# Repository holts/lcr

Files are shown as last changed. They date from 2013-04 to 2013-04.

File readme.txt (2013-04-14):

适合业余爱好者DIY高精度数字电桥 

http://www.crystalradio.cn/thread-231933-131-1.html
http://bbs.38hot.net/read.php?tid=13531
http://www.ourdev.cn/thread-5152439-1-2.html

程序为矿坛下的 gyp2000更改的 1602 V5.5

/**
  @page exampletemplate Project Example Template
  
  @verbatim
  ******************** (C) COPYRIGHT 2011 STMicroelectronics *******************
  * @file    readme.txt 
  * @author  MCD Application Team
  * @version V2.1.0
  * @date    18-November-2011
  * @brief   This sub-directory contains all the user-modifiable files 
  *          needed to create a new project linked with the STM8S/A  
  *          Standard Peripheral Library.
  ******************************************************************************
  * THE PRESENT FIRMWARE WHICH IS FOR GUIDANCE ONLY AIMS AT PROVIDING CUSTOMERS
  * WITH CODING INFORMATION REGARDING THEIR PRODUCTS IN ORDER FOR THEM TO SAVE
  * TIME. AS A RESULT, STMICROELECTRONICS SHALL NOT BE HELD LIABLE FOR ANY
  * DIRECT, INDIRECT OR CONSEQUENTIAL DAMAGES WITH RESPECT TO ANY CLAIMS ARISING
  * FROM THE CONTENT OF SUCH FIRMWARE AND/OR THE USE MADE BY CUSTOMERS OF THE
  * CODING INFORMATION CONTAINED HEREIN IN CONNECTION WITH THEIR PRODUCTS.
  ******************************************************************************
   @endverbatim

@par Project Example Template Description 

This example is used as a template that can be used as reference to build any new 
firmware development for all STM8S and STM8A product devices using the STM8S/A 
Standard Peripherals Library.

@par Directory contents 

This folder contains standard template projects for EWSTM8, STVD with Cosmic, 
STVD with raisonance and RIDE toolchains that compile the needed STM8S/A Standard
Peripheral's drivers plus all the user-modifiable files that are necessary to 
create a new project. 

  - Project/led/inc/stm8s_conf.h    Library Configuration file

  - Project/led/src/stm8s_it.c:     Source file containing the interrupt handlers (the 
                                     function bodies are empty in this template).

  - Project/led/inc/stm8s_it.h      Header file including all interrupt handlers prototypes.

  - Project/led/src/main.c          Main program
          
 @note
  - High-Density STM8A devices are the STM8AF52xx STM8AF6269/8x/Ax,
    STM8AF51xx, and STM8AF6169/7x/8x/9x/Ax microcontrollers where the Flash memory
    density ranges between 32 to 128 Kbytes
  - Medium-Density STM8A devices are the STM8AF622x/4x, STM8AF6266/68,
    STM8AF612x/4x, and STM8AF6166/68 microcontrollers where the Flash memory 
    density ranges between 8 to 32 Kbytes
  - High-Density STM8S devices are the STM8S207xx, STM8S007 and STM8S208xx microcontrollers
    where the Flash memory density ranges between 32 to 128 Kbytes.
  - Medium-Density STM8S devices are the STM8S105x and STM8S005 microcontrollers
    where the Flash memory density ranges between 16 to 32-Kbytes.
  - Low-Density STM8S devices are the STM8S103xx, STM8S003 and STM8S903xx microcontrollers
    where the Flash density is 8 Kbytes.
   
 * <h3><center>&copy; COPYRIGHT 2011 STMicroelectronics</center></h3>
 */

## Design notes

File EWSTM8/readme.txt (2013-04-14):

/**
  @page ewstm8 EWSTM8 Project Template for STM8S/A product devices
  
  @verbatim
  ******************* (C) COPYRIGHT 2011 STMicroelectronics ********************
  * @file    readme.txt
  * @author  MCD Application Team
  * @version V2.1.0
  * @date    18-November-2011
  * @brief   This sub-directory contains all the user-modifiable files needed
  *          to create a new project linked with the STM8S/A Standard Peripheral 
  *          Library and working with IAR Embedded Workbench for STM8 (EWSTM8)
  *          software toolchain.
  ******************************************************************************
  * THE PRESENT FIRMWARE WHICH IS FOR GUIDANCE ONLY AIMS AT PROVIDING CUSTOMERS
  * WITH CODING INFORMATION REGARDING THEIR PRODUCTS IN ORDER FOR THEM TO SAVE
  * TIME. AS A RESULT, STMICROELECTRONICS SHALL NOT BE HELD LIABLE FOR ANY
  * DIRECT, INDIRECT OR CONSEQUENTIAL DAMAGES WITH RESPECT TO ANY CLAIMS ARISING
  * FROM THE CONTENT OF SUCH FIRMWARE AND/OR THE USE MADE BY CUSTOMERS OF THE
  * CODING INFORMATION CONTAINED HEREIN IN CONNECTION WITH THEIR PRODUCTS.
  ******************************************************************************
  @endverbatim
 
 @par Directory contents

 - project .ewd/.eww/.ewp: A pre-configured project file with the provided library 
                           structure that produces an executable image with IAR 
                           Embedded Workbench.

 @par How to use it ?

 - Open the Project.eww workspace.
 - In the workspace toolbar select the project configuration:
     - stm8s103: to configure the project for STM8S103 Low-density devices. 
     - stm8s903: to configure the project for STM8S903 Low-density devices.
     - stm8s105: to configure the project for STM8S Medium-density devices.
     - stm8s207: to configure the project for STM8S207 High-density devices.
     - stm8s208: to configure the project for STM8S208 High-density devices.
     - stm8af52ax: to configure the project for STM8AF52Ax High-density devices.
     - stm8af62ax: to configure the project for STM8AF62Ax High-density devices.
     - stm8af626x: to configure the project for STM8A Medium-density devices.
     @note The needed define symbols for these configurations are already declared in the
           preprocessor section.

 - Rebuild all files: Project->Rebuild all
 - Load project image: Project->Debug
 - Run program: Debug->Go(F5)

  @note
  - High-Density STM8A devices are the STM8AF52xx STM8AF6269/8x/Ax,
    STM8AF51xx, and STM8AF6169/7x/8x/9x/Ax microcontrollers where the Flash memory
    density ranges between 32 to 128 Kbytes
  - Medium-Density STM8A devices are the STM8AF622x/4x, STM8AF6266/68,
    STM8AF612x/4x, and STM8AF6166/68 microcontrollers where the Flash memory 
    density ranges between 8 to 32 Kbytes
  - High-Density STM8S devices are the STM8S207xx, STM8S007 and STM8S208xx microcontrollers
    where the Flash memory density ranges between 32 to 128 Kbytes.
  - Medium-Density STM8S devices are the STM8S105x and STM8S005 microcontrollers
    where the Flash memory density ranges between 16 to 32-Kbytes.
  - Low-Density STM8S devices are the STM8S103xx, STM8S003 and STM8S903xx microcontrollers
    where the Flash density is 8 Kbytes.
   
 * <h3><center>&copy; COPYRIGHT 2011 STMicroelectronics</center></h3>
 */

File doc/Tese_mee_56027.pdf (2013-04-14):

## Dissertation submitted for obtaining the degree of Master in Electronic Engineering

## Impedance Measuring System based on a dsPIC

## José Carlos Sequeira Martins dos Santos

## November 2009

### President : Prof. Moisés Simões Piedade Supervisor: Prof. Pedro Miguel Pinto Ramos Members: Prof. Rui Manuel Rodrigues Rocha

## Jury

i

# Acknowledgements

Above all, I would like to thank my parents, my sister and the rest of my family for the

patience and support demonstrated throughout these five long years of the course. Without

them I could not have made it so far.

I want to thank my coworkers and friends for always being there to help me in the

difficult moments and for providing an excellent work environment. They are certain one of the

best group of people I ever had the pleasure of meeting.

I thank Professor Pedro Ramos for the support and encouragement given throughout

the work, and for giving me the opportunity to develop it.

Finally I would like to thank Professor Moisés Piedade for is undying efforts for creating

the necessary conditions for all to develop their work.

Thank you all.

ii

# Abstract

Impedance measurement is currently one of the research and development areas under

the work developed by the Instrumentation and Measurement Group of the Institute of

Telecommunications. The existing measurement systems are either too costly or don’t have

enough accuracy and make measurements in a reduced frequency range.

This work is related to a project that is underway: IMPANA – Development and

implementation of an impedance analyzer based on analog to digital conversion and powerful

signal processing algorithms (Financed by the Foundation for Science and Technology,

PTDC/EEA-ELC/72875/2006 from 01-Sep-2006 to 31-Aug-2010).

With the execution of this work one seeks to obtain a device capable of making

impedance measurements at multiple frequencies. The device is based on a dsPIC (Digital

Signal Peripheral Interface Controller) from Microchip as a central processing unit. A DDS

(Direct Digital Synthesizer) is used to generate the stimulus signal of the measurement circuit,

which has the reference impedance and the impedance under measurement. The voltage

across the two impedances is amplified by programmable gain instrumentation amplifiers,

whose outputs will then be digitized by analog to digital converters. The signal processing for

the determination of the unknown impedance is performed using a sine-fitting algorithm. The

dsPIC is connected through RS-232 to a personal computer (PC), where the user can monitor

the resulting samples of the measurement and view the measurement results.

Keywords: Impedance measurement, dsPIC, ADC, Sine-fitting

iii

# Resumo

A medição de impedâncias é actualmente uma das áreas de investigação e

desenvolvimento, no âmbito dos trabalhos desenvolvidos pelo Grupo de Instrumentação e

Medidas no Instituto de Telecomunicações. Os sistemas de medição existentes ou são

demasiado dispendiosos ou não têm exactidão suficiente e efectuam medições numa gama de

frequências reduzida.

Este trabalho enquadra-se num projecto que se encontra a decorrer: IMPANA –

Development and implementation of an impedance analyzer based on analog to digital

conversion and powerful signal processing algorithms (Financiado pela Fundação para a

Ciência e Tecnologia, PTDC/EEA-ELC/72875/2006 de 01-Set-2006 a 31-Ago-2010).

Com a execução deste trabalho pretende-se obter um dispositivo capaz de efectuar

medições de impedâncias a diversas frequências. O dispositivo é baseado num dsPIC (Digital Signal Peripheral Interface Controller) da Microchip como unidade central de processamento. É

utilizado um DDS (Direct Digital Synthesizer), sendo responsável por gerar o sinal de estímulo

do circuito de medição, que tem a impedância de referência e a impedância a medir. As

tensões aos terminais das duas impedâncias são amplificadas por amplificadores de

instrumentação de ganho programável, cujas saídas são digitalizadas por conversores

analógico-digitais. O processamento de sinal necessário para a determinação da impedância

desconhecida é efectuado recorrendo ao algoritmo de adaptação de sinusóides. O dsPIC é

ligado através de RS-232 a um computador pessoal (PC), onde o utilizador pode monitorizar as

amostras resultantes da medição e visualizar os resultados da medição.

Palavras – Chave: Medição de impedâncias, dsPIC, ADC, Sine-fitting

iv

# Table of Contents

v

vi

# List of Figures

Fig. 1.2 - Representation of inductive and capacitive reactance in the impedance vector plane. 2

Fig. 1.3 - An example of linear (a) and rotational (b) EIM measurements being performed on a

Fig. 2.4 - RF I-V method. (a) Low impedance measurement; (b) High impedance measurement

Fig. 3.1 - Measurement circuit. | is the impedance under measurement and | is the reference

Fig. 3.2 – Development tools for the work. (a) Explorer 16 Development Board; (b) MPLAB ICD

Fig. 3.5 - High-pass filter used to eliminate the DC component from the output signal of the

Fig. 3.10 - Circuit of a differential amplifier used to add a DC offset to the signal to acquire. .... 21

Fig. 4.2 - Behavior of an acquired signal spectrum in the case of no under sampling and in the

vii

Fig. D.1 - Schematic of the complete system. Square 3 represents the hardware for the USB

viii

# List of Tables

ix

# Acronyms

Acronym | Meaning
ADC | Analog to Digital Converter
ASCII | American Standard Code for Information Interchange
DAC | Digital to Analog Converter
DC | Direct Current
DDS | Direct Digital Synthesizer
DSC | Digital Signal Controller
DSP | Digital Signal Processor
dsPIC | Digital Signal Peripheral Interface Controller
FFT | Fast Fourier Transform
IDE | Integrated Development Environment
IpDFT | Interpolated Discrete Fourier Transform
MCU | Microcontroller
MIPS | Million Instruction Per Second
OP-AMP | Operational Amplifier
PC | Personal Computer
PCB | Printed Circuit Board
PGIA | Programmable Gain Instrumentation Amplifier
RAM | Random Access Memory
ROM | Read Only Memory
SPI | Serial Peripheral Interface
THD | Total Harmonic Distortion

# 1 – Introduction

## 1.1– Impedance Concepts Overview

Impedance is an important parameter used to characterize electronic circuits,

components, and the materials used to make components [1]. Impedance (Z) is generally

defined as the total opposition a device or circuit offers to the flow of an alternating current (AC)

at a given frequency, and is represented as a complex quantity which can be graphically

represented on a vector plane – Fig. 1.1. An impedance vector consists of a real part

(resistance, R) and an imaginary part (reactance, X).

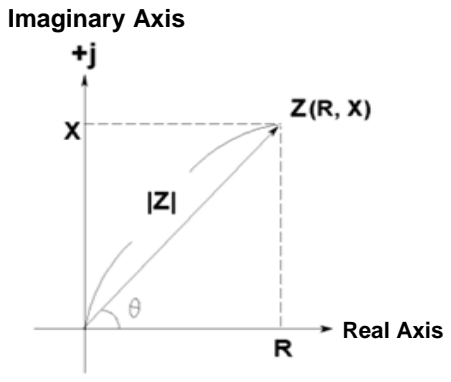
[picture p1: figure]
Real Axis; Imaginary Axis

Fig. 1.1 - Impedance vector plane (taken from [1]).

Impedance can be expressed using the rectangular form,

or the polar form as a magnitude and phase angle,

Equations (1.3) to (1.6) show the mathematical relationships between R, X, |Z| and θ.

The unit of impedance is the ohm (Ω).

Reactance can take two forms: inductive (XL) and capacitive (XC). Fig. 1.2 represents

the two possible forms of reactance and the correspondent representation in the impedance

vector plane for a given frequency.

Fig. 1.2 - Representation of inductive and capacitive reactance in the impedance vector plane.

## 1.2– Applications of Impedance Measurements

As the world of technology evolves, so does its need for improved measurement

techniques. One of the major areas of investigation that has been growing for the past few

years is impedance measurement. With a wide spectrum of applications, from medicine to

electronics, impedance measurement is surely an area worth researching.

In the field of medicine, impedance measurement can be used in electrical impedance

myography (EIM), which is a non-invasive technique for neuromuscular assessment [2], [3]. It

enables the detection of degenerative neuromuscular diseases. Measurements can be taken

painlessly and non-invasively using electrodes that are placed on top of the skin. They can also

be taken from different parts of the body at the bedside. In this technique, a low-intensity

alternating current is applied to a muscle and the consequent voltage difference is evaluated.

From these measurements one can calculate the impedance of the underlying muscle and

make inference about its structure.

There are two main methods used in this technique: linear EIM and rotational EIM.

Linear EIM involves placing multiple pairs of voltage electrodes in a line directly above the

muscle or muscle group of interest – Fig. 1.3(a). The current electrodes are placed so that

current must flow in parallel to this line. The voltages at each point along the muscle are

compared during analysis. Both single frequency (typically 50 kHz) and multi-frequency

measurements can be taken.

Rotational EIM measures impedance at multiple angles relative to the direction of

muscle fibers – Fig. 1.3(b). Both the current and voltage electrodes need to be rotated as they

must be kept in line with each other at all angles to control the direction of current flow. For this

method multi-frequency measurements are usually taken and then the average phase across all

frequencies is compared at each different angle.

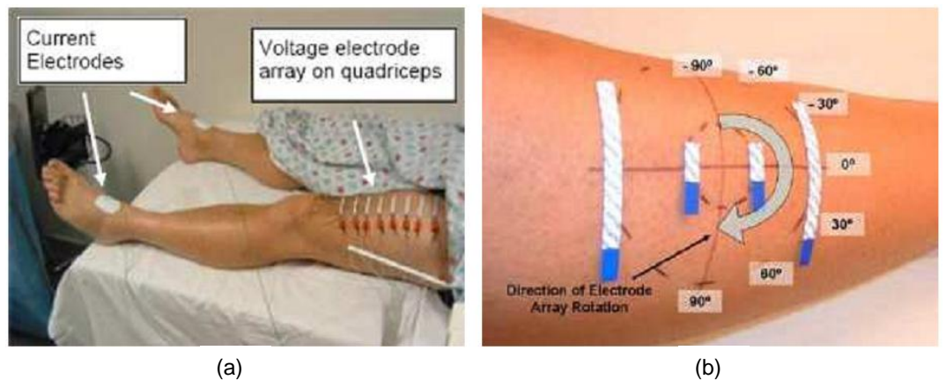
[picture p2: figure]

Fig. 1.3 - An example of linear (a) and rotational (b) EIM measurements being performed on a patient (taken from [3]).

Impedance measurement can also play an important part in civil engineering. It can be

used to measure the level of corrosion in some materials such as reinforced steel in concrete

[4]. A concrete Surface-based Measurement Method (SMM) is used as nondestructive

technique to determine the deterioration of structures and study the corrosion process. The

method is able to determine the corrosion state of the reinforcing bars, as well as the resistivity

of the concrete itself, from the concrete surface and with no need of connection to the

reinforcement. It uses an array of four electrodes, equally spaced, and placed on the surface of

the concrete to indirectly measure the frequency-dependent impedance between the reinforcing

steel bars and the concrete – Fig. 1.4. Alternating current, varied over a wide range of

frequencies, is injected between the two outer electrodes, and the voltage difference produced

by the current flow is measured across the two inner electrodes. This voltage presents an angle

phase shift with respect to the current. As the current is injected into the concrete, the steel bar

surface becomes polarized creating a net dipole which is added to the voltage read by the inner

electrodes – Fig. 1.5.

It is important to notice that the measured impedance on the concrete surface does not

reflect directly the interfacial impedance, because it is influenced by the concrete resistivity.

However, a change in the corrosion state of a steel bar, will be reflected in the measurement on

the concrete surface, and given the concrete resistivity and measurement geometry, the

impedance response is unique to each interfacial impedance.

Fig. 1.4 - Four-electrode array placed on the concrete surface (taken from [4]).

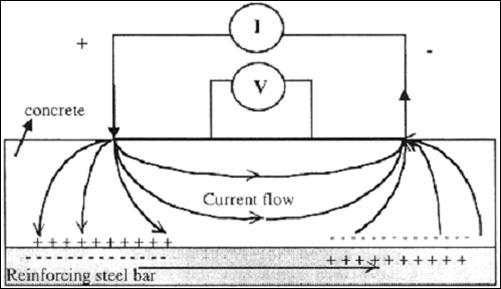
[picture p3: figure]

Fig. 1.5 - Net dipole created by the four-electrode array (taken from [4]).

## 1.3– Motivation

The technological advances of the past few years have improved the performance of

data acquisition systems to a point where it is possible to implement cheaper ways to make the

same measurements as dedicated expensive equipment, without relevant degradation of the

system accuracy.

The continuous improvement in performance of new devices, such as Analog to Digital

Converters (ADCs), combined with more powerful signal processing techniques, are some of

the factors that have contributed to this fact.

Typical measuring techniques/instruments are either too costly, or don’t have enough

accuracy and have a reduced frequency range. Agilent Technologies is one of the leading

companies for measurement systems. Its simplest impedance measuring system [5] covers

frequencies from 40 Hz up to 110 MHz with a basic accuracy of 0.08 %. However, its price of

nearly 30.000€ makes the system well beyond the budget capabilities of many companies and

research institutes.

Therefore there has been an increasing demand for low cost impedance measuring

systems capable of performing measurements at a broad range of frequencies but still with

comparable accuracy to that of sophisticated impedance measurement equipment.

## 1.4– Work Goals

This work seeks to develop, implement and characterize a low-cost device capable of

measuring impedances at a wide range of frequencies by using ADCs and a dsPIC as a central

processing unit to both control all the necessary hardware of the measuring circuit and run the

sine fitting algorithm necessary to the proper measurement of the impedance. A personal

computer is also used, which acts as interface between the user and the device, allowing the

monitoring of the acquired samples.

The device has to be able to measure impedances in the frequency range from 500 Hz

to 200 kHz. The amplitude of the impedances to be measured is intended to be between 100 Ω

and 10 kΩ.

The dsPIC is responsible for: i) controlling the stimulus module of the measurement

circuit through a DDS which is responsible for generating the sine signal with the measurement

frequency; ii) controlling the programmable gain instrumentation amplifiers (PGIAs) that amplify

the voltage at the terminals of the two impedances (reference impedance and impedance under

measurement); iii) controlling and communicating with the ADCs responsible for the

digitalization of the output voltage from the PGIAs; iv) applying the algorithm to determine the

amplitudes and phases of the sinusoidal signals across each impedance (sine-fitting); v)

applying the algorithms to correct systematic errors; vi) transmitting the results to a PC through

a RS-232 connection.

In the end the user will be able to control the device in order to decide at which

frequency he wants to perform the impedance measurement.

## 1.5- Thesis Organization

This thesis is organized as follows:

In Section 2, the State Of The Art for impedance measurement systems is presented. It

is given an overview of the existing impedance measurement methods. A few points regarding

sine-fitting algorithms are discussed and finally it is presented a new impedance measurement

method that is currently under development.

In Section 3 it is presented the system’s architecture, where the measurement circuit

and method is explained, along with all the hardware used in the system.

Section 4 describes in detail all the algorithms implemented, for proper measurement of

the unknown impedance.

In Section 5 the implemented control software running on a PC is described.

In Section 6 the experimental results obtained by the device are compared to the results

obtained with a commercially available device.

The conclusions of the work are presented in Section 7.

Finally, Section 8 describes the proposed future work.

# 2 – State Of The Art

Impedance measurement systems are used to test electronic components, circuits and

materials. They can also be used to measure sensor’s outputs that translate physical quantities

into electrical impedance.

## 2.1– Impedance Measurement Methods

Several impedance measurement methods exist. Traditional methods include: bridge,

resonant, I-V, RF I-V, network analysis and auto balancing bridge [1].

The bridge method applies the setup presented in Fig. 2.1.

Fig. 2.1 - Bridge method setup (taken from [1]).

When no current flows through the detector (D), the value of the unknown impedance

Zx can be obtained by the relationship of the other bridge elements by

Various types of bridge circuits, employing combinations of L, C, and R components as

the bridge elements, are used for various applications.

This is a low cost method with a wide frequency coverage (DC to 300 MHz) by using

different types of bridges. However, it needs to be manually balanced by experienced

technicians.

In the resonant method, the setup from Fig. 2.2 is used.

Fig. 2.2 - Resonant method setup (taken from [1]).

When the circuit is adjusted to resonance by adjusting the tuning capacitor C, the

unknown impedance Lx and Rx values are obtained from the test frequency, the C value, and

the Q value. Q represents the quality factor of the inductance. Q is measured directly using a

voltmeter placed across the tuning capacitor. Because the loss of the measurement circuit is

very low, Q values as high as 1000 can be measured.

It presents a good Q accuracy up to high Q, but the need for tuning to resonance and its

low impedance measurement accuracy are clear disadvantages of this method. It has an

applicable frequency range from 10 kHz to 70 MHz.

The I-V or volt-ampere method has the measurement setup presented in Fig. 2.3.

Fig. 2.3 - I-V method setup (taken from [1]).

The unknown impedance Zx can be calculated by using the measured voltages V1 and

V2 – equation (2.2).

The current value I is calculated using the voltage measurement (V2) across an

accurately known low value resistor, R. In practice a low-loss transformer is used in place of R

to prevent the effects caused by placing a low value resistor in the circuit. The transformer,

however, limits the low end of the applicable frequency range (10 kHz to 100 MHz).

This method has the advantage of being able to perform a grounded device

measurement and is suitable for probe type test needs.

The measurement setup for the RF I-V method is presented in Fig. 2.4.

Fig. 2.4 - RF I-V method. (a) Low impedance measurement; (b) High impedance measurement (taken from [1]).

The RF I-V measurement method is based on the same principle as the I-V method, but

it is configured in a different way by using an impedance matched measurement circuit (50 Ω)

and a precision coaxial test port for operation at higher frequencies. There are two types of

configurations which are suited for low impedance – Fig. 2.4(a), and high impedance – Fig.

2.4(b), measurements. The impedance Zx is derived from the measured voltage values V1 and

V2, as illustrated. Equation (2.3) refers to the low impedance measurement arrangement and

(2.4) refers to the high impedance measurement arrangement.

Similarly to the I-V method, the current that flows through Zx is calculated from the

voltage measurement across a known low value resistor, R. Just like before, in practice, a low

loss transformer is used in place of the low value resistor, R. The low end of the frequency

range of this method (1 MHz to 3 GHz) is limited by this transformer.

This method presents a high accuracy (typically 1%) and a wide impedance range at

high frequencies.

The network analysis method has the measurement setup presented in Fig. 2.5.

Fig. 2.5 - Network analysis method setup (taken from [1]).

In this method the reflection coefficient is obtained by measuring the ratio between the

incident signal and the reflected signal. A directional coupler or bridge is used to detect the

reflected signal and a network analyzer is used to supply and measure the signals. Since this

method measures reflection at the impedance Zx, it is usable in a higher frequency range

(300 kHz and above).

This method presents a good accuracy when the unknown impedance is close to the

characteristic impedance of the network, but it has the disadvantage of requiring a recalibration

procedure when the measurement frequency changes. It also has a narrow impedance

measurement range.

The auto balancing bridge method setup is shown in Fig. 2.6.

Fig. 2.6 - Auto balancing bridge setup (taken from [1]).

The current, flowing through the impedance Zx, also flows through the resistor R. The

potential at the “L” point is maintained at zero volts (thus called a “virtual ground”), because the

current through R balances with the Zx current by operation of the I-V converter amplifier. The

Zx impedance is calculated by using the voltage measured at the “H” point and the voltage

across R.

In practice, the configuration of the auto balancing bridge differs for each type of

instrument. Generally LCR meters, in a low frequency range typically below 100 kHz, employ a

simple operational amplifier for its I-V converter. This type of instrument has a disadvantage in

accuracy, at high frequencies, because of the amplifier’s limits in terms of performance.

Wideband LCR meters and impedance analyzers employ an I-V converter consisting of

sophisticated null detector, phase detector, integrator (loop filter) and vector modulator to

ensure a high accuracy for a broad frequency range over 1 MHz. This type of instrument can attain a maximum measurement frequency of 110 MHz. These instruments have a minimum

measurement frequency of about 20 Hz.

This method has a high accuracy over a wide impedance measurement range and is

capable of performing a grounded device measurement.

Agilent Technologies, one of the leading companies of the instrumentation market, has

several commercially available products that apply some of the methods described above. The

4287A RF LCR Meter [6] uses an RF I-V method, the 4395A Network/Spectrum/Impedance

Analyzer [7] uses a network analysis method and the 4294A Precision Impedance Analyzer [5]

uses an auto balancing bridge method.

## 2.2– Sine-Fitting Algorithms

The objective of sine-fitting algorithms is to obtain a set of parameters corresponding to

the analytical expression of a sine signal while minimizing the sum of the squared errors

between the estimated parameters and the acquired samples.

The three-parameter and the four-parameter sine-fitting algorithms were standardized in

[8]. The first is a non-iterative algorithm that with the knowledge of the frequency estimates the

amplitude, the phase and the DC component of the signal. The second also estimates the

frequency of the signal, but requires an iterative process to obtain the best estimation of the

parameters. Because it uses an iterative process, the initial estimates of the parameters are

critical for the convergence of the algorithm. In applications that use two channels with a

common frequency, which is the case of this work, all the information from both records should

be used to obtain a better estimative of the frequency. This can be done using a seven-

parameter sine-fitting algorithm [9], which is an iterative algorithm similar to the four-parameter

algorithm. The difference is that the seven-parameter algorithm estimates the amplitude, phase

and DC component of both signals, plus the common frequency. The effectiveness of this

algorithm was demonstrated in [10], when compared with the application of two four-parameter

algorithms.

The seven-parameter sine-fitting algorithm was the selected algorithm for the purposes

of this work and it will be described in more detail later on.

## 2.3– New Impedance Measurement Method

In many applications it is necessary to accurately measure an unknown impedance

corresponding to a sensor output. In [11] a new method for impedance measurements using

DSP-based ellipse-fitting algorithms is described. This method uses a sine wave generator to

supply current to the serial circuit composed by the reference impedance and the impedance to

be measured. It also uses two instrumentation amplifiers that sense the differential voltages at

the reference impedance and the impedance to be measured, a two channel ADC that digitizes

the signals coming from the instrumentation amplifiers and a DSP (Digital Signal Processor) as a central processing unit. A personal computer is also used to communicate with the DSP

through an RS-232 connection. Fig. 2.7 shows the measurement setup.

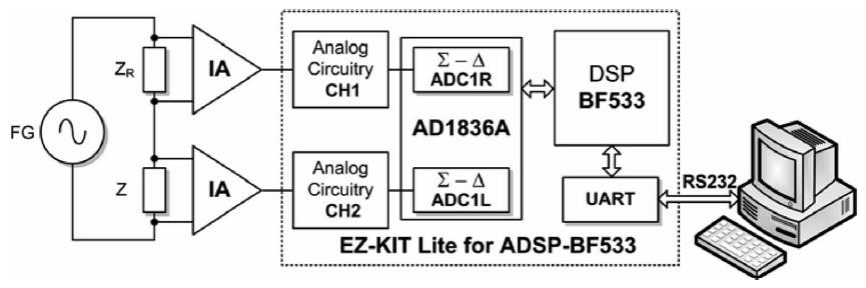
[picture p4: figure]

Fig. 2.7 - Measurement setup (taken from [11]).

In [11] the algorithm used to perform the signal processing is the ellipse-fitting algorithm.

The ellipse-fitting algorithm is not iterative since it does not estimate the frequency of the

signals. Because the frequency is imposed by the generator, there is no need to estimate it.

This makes the ellipse-fitting algorithm very efficient, and since it can be modified from its

original form [12] to have very low memory requirements, it turns out to be a very fast signal

processing algorithm allowing the system to perform high speed measurements.

This methodology, given the nature of the devices used in the system, is a low-cost

alternative to dedicated impedance measurement equipment, but with comparable accuracy.

This thesis applies a measurement method similar to that described above, except for

the algorithm responsible for the signal processing. In the case of this thesis the selected

algorithm is the seven-parameter sine-fitting algorithm. The measurement setup used in this

thesis will be explained in detail later on.

# 3 – System’s Architecture

## 3.1 – Measurement Circuit and Method

The impedance measurement circuit used to ascertain the value of the unknown

impedance is presented in Fig. 3.1.

Fig. 3.1 - Measurement circuit. | is the impedance under measurement and | is the reference impedance.

The measurement method is based in the volt-ampere method [1], in which the module

of the unknown impedance can be determined by knowing the module of the reference

impedance and the ratio between the amplitude of the sine signal across the impedance under

measurement and the amplitude of the sine signal across the reference impedance. The phase

angle of the unknown impedance is calculated based in the phase angle of the reference

impedance and the phase difference between the sine signal across the impedance under

measurement and the sine signal across the reference impedance [13]. The method used is

similar to that in [11], but in this case a dsPIC is used as a processing unit and a DDS is used to

inject current in the circuit.

The measurement procedure is done according to the following steps:

(i) The dsPIC controls the DDS in order to generate a sine wave with the user-

defined measurement frequency.

(ii) The dsPIC selects the gains of the amplifiers according to the magnitudes of

the signals across the reference impedance and the impedance under

measurement.

(iii) The dsPIC controls the ADCs to acquire simultaneously the samples (in this

case 1024 per channel) of the output voltage of the PGIAs, which amplify the

signals across the reference impedance (PGIA 1) and the unknown impedance

(PGIA 2). The gains of both amplifiers are set by the dsPIC to maximize the

amplitudes of the signals, but with care to avoid saturation of the digitizing

channels.

(iv) | A seven parameter sine-fitting algorithm is applied in order to determine the
amplitudes | and phases | of the sine waves that best fit the acquired
samples of both channels ( | ).

(v) The modulus and phase angle of the impedance under measurement are

calculated by

Once all the calculations are done, the experimental results of the measurement are

transmitted to the PC.

The entire measurement circuit is represented in the schematic from Fig. C.1 in

appendix C.

## 3.2 – Processing Unit

The processing unit used in the device is a dsPIC which is a Digital Signal Controller

(DSC). A DSC is a single-chip, embedded controller that integrates the control attributes of a

Microcontroller (MCU) with the computation and throughput capabilities of a Digital Signal

Processor (DSP) in a single core. In terms of performance and price, a dsPIC is somewhere in

the middle of the PIC MCU (in the low end) and the DSP (in the high end), and so it achieves

the best of both worlds making it perfect for this embedded control application.

The dsPIC used in this work is a 16-bit dsPIC33FJ256GP710 microcontroller from

Microchip - Fig. 3.2(c). It has a throughput up to 40 MIPS, 256 kB of flash program memory and

30 kB of RAM (Random Access Memory). It also includes two 12-bit ADCs capable of

conversion speeds up to 500 kS/s.

The Explorer 16 Development Board from Microchip - Fig. 3.2(a), in which the dsPIC is

connected to, is used as a prototyping tool to help implement the device. The board allows easy

connection to an MPLAB ICD 2 In-Circuit Debugger - Fig. 3.2(b). This is a development tool

allowing the programming of the dsPIC, and is capable of debugging ASM and C source code.

The application code for the device is written in C language on the MPLAB Integrated

Development Environment (IDE), and then it is loaded to the dsPIC using the MPLAB ICD 2.

The total program memory required for the execution of the developed code for this

work is 16578 bytes, and the total data memory is 20850 bytes. These memory requirements

are well within the memory capabilities of the dsPIC. The data memory required is so high given

the nature of some of the algorithms used in this work. Each algorithm and their memory

requirements will be explained in more detail in Section 4.

The hardware associated with the processing unit is represented in square 1 in the

schematic from Fig. D.1 in appendix D.

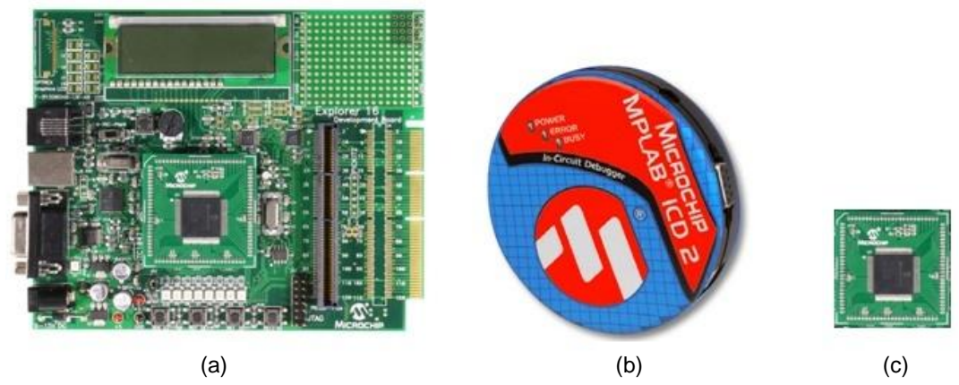
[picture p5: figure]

Fig. 3.2 – Development tools for the work. (a) Explorer 16 Development Board; (b) MPLAB ICD 2 In-Circuit

Debugger; (c) 16-bit dsPIC33FJ256GP710.

## 3.3– Stimulus Module

The module used to stimulate the measurement circuit is a DDS. A DDS is an electronic

programmable waveform generator, which produces a signal from a fixed-frequency clock

source. The waveform is digitally generated by using sampling techniques. Typically it is used to

generate a sine wave, although it can be used to synthesize any other periodic waveforms such

as triangular and square signals.

A DDS is basically composed by a phase accumulator, a phase to amplitude converter

and a digital to analog converter (DAC). A low-pass filter may also be included to eliminate

unwanted high frequency spectral components from the analog output. Fig. 3.3 shows the block

diagram of a general DDS.

Fig. 3.3 - Block diagram of a general DDS.

The DDS operation consists of the following: the phase accumulator is incremented by

using a clocked binary adder, and each value corresponds to a specific phase value between 0

and 2π. The phase to amplitude converter translates these values into a digital representation

of the desired waveform by using, for example, a look-up table implemented in a ROM (Read

Only Memory). The digital output of the phase to amplitude converter is then converted to an analog output by the DAC. The phase information is used because unlike the magnitude, which

is nonlinear and not easy to generate, the angular information of a sine wave is linear in nature.

That is, the phase angle rotates through a fixed angle for each unit of time.

A DDS module can be very useful in various types of sensing, actuation, and

modulation applications where it may be necessary to produce a locally controlled signal.

In this work the AD9833 from Analog Devices is used to produce the sine signal with the

desired measurement frequency in order to inject current to the measurement circuit. It is

capable of producing sine, triangle and square waveforms with an output frequency range from

0 MHz to 12.5 MHz, and the amplitude of the output signal is typically 0.6 Vpp. The module is

also compatible with SPI interface, allowing its control by a microcontroller, in this case the

dsPIC.

The DDS output sine signal with a frequency of 1 kHz and the correspondent FFT is

presented in Fig. 3.4.

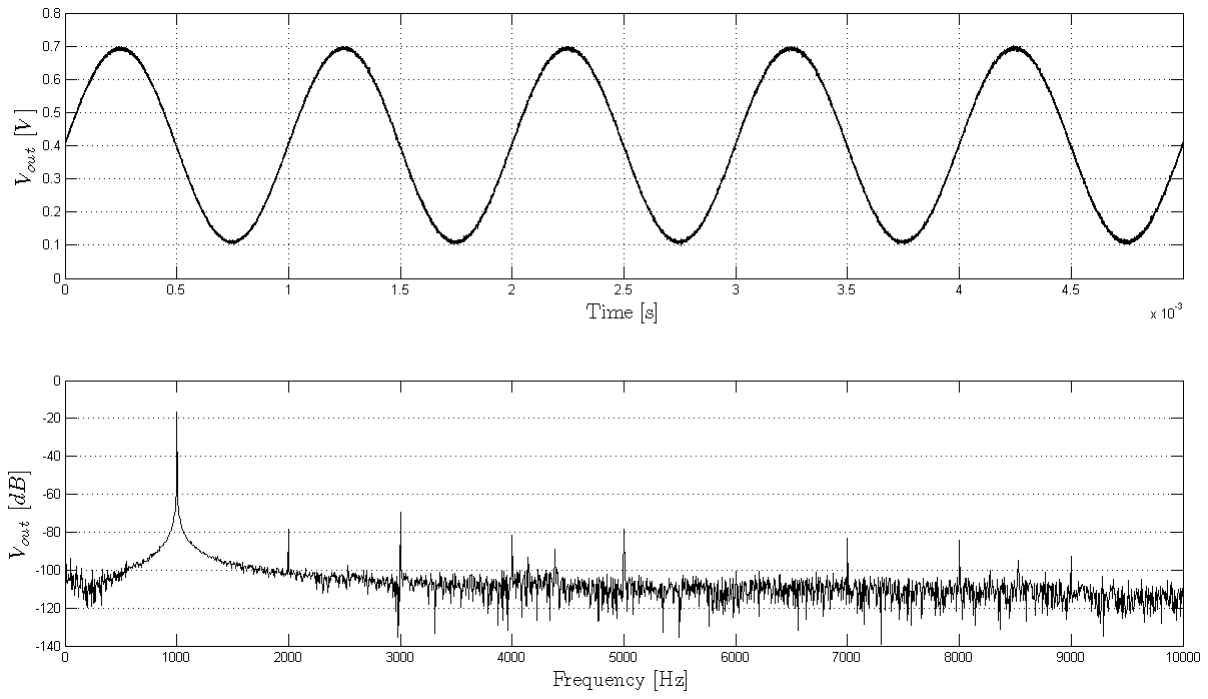
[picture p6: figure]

Fig. 3.4 - Output signal and correspondent FFT from the DDS at 1 kHz.

The signal was measured through an Agilent 54622D Mixed Signal Oscilloscope from

Agilent Technologies. Two million samples of the signal were acquired and transferred to a

computer and saved in a text file. In order to obtain the FFT of the signal, the samples were

processed in the MATLAB environment where it was also possible to estimate the Total

Harmonic Distortion (THD) of the sine signal. The estimated THD value is 51.175365 dB. The

graphics represented in Fig. 3.4 were also plotted in MATLAB.

The AD9833 DDS does not produce a bipolar signal output, which means it has a DC

component in the output signal. For the purposes of this work it was necessary to apply a

bipolar signal to the measurement circuit, so it was necessary to implement a high-pass filter

with a low cutoff frequency to eliminate the DC component. The implemented filter is presented

in Fig. 3.5.

Fig. 3.5 - High-pass filter used to eliminate the DC component from the output signal of the DDS.

The cutoff frequency of the filter is given by

which is well beneath the range of frequencies intended for this work, 500 Hz to 200 kHz.

The delay of the implemented filter is not relevant for the range of frequencies

considered in this work.

Because the magnitude of the output signal is so low (0.6 Vpp), it was decided to add

an inverting amplifier circuit to the output of the filter to amplify the signal from the DDS. The

implemented circuit is shown in Fig. 3.6.

Fig. 3.6 - Inverting amplifier circuit used to add gain to the output signal of the DDS.

The gain of the inverting amplifier circuit is given by equation (3.4), which results in a

signal magnitude of 3 Vpp.

The operational amplifier used was the OP484 from Analog Devices.

The closed-loop bandwidth of the amplifier is about 1 MHz, which is suitable for the

frequency range used in this work.

The stimulus module of the measurement circuit is represented in square 1 in the

schematic from Fig. C.1 in appendix C.

## 3.4– Programmable Gain Instrumentation Amplifiers

An instrumentation amplifier is a differential-input amplifier [14], used for the accurate

amplification of the difference between two voltages. It presents a high Common Mode

Rejection Ratio (CMRR), allowing its use in circuits with high common-mode voltages and small

differential voltages. It has a high input impedance, which allows its insertion in a measurement

circuit with negligible influence over the circuit. Because of this, the instrumentation amplifier is

perfect for data acquisition and measurement applications. It differs from an op-amp, which

ideally has infinite open-loop gain and must be used in conjunction with external elements to

define the closed-loop transfer function. Traditionally an instrumentation amplifier is composed

by three OP-AMPs and its circuit is presented in Fig. 3.7.

Fig. 3.7 - Typical instrumentation amplifier circuit.

If | k, then

So, the overall gain of the instrumentation amplifier can be adjusted through the

variation of a single resistor (R1).

In this work an AD8250 programmable gain instrumentation amplifier from Analog

Devices was used. It allows four programmable gains: 1, 2, 5 and 10. The gain is digitally set by the processing unit in order to maximize the voltages at the ADCs inputs, while avoiding

saturation of the digitizing channels. This is done in order to obtain a better resolution of the

acquired signals.

Gain control in the AD8250 is achieved by switching resistors in an internal, precision

resistor array. The (write enable), A0 (LSB gain selection pin) and A1 (MSB gain selection

pin) digital inputs of the device control the desired gain.

There are two methods through which the gain of the AD8250 can be set: the

transparent gain mode and the latched gain mode. In the transparent gain mode is tied to

the negative supply voltage (-VS) and any change in the voltage applied to A0 and A1 from logic

low to logic high, or vice versa, immediately results in a gain change. Table 3.1 is the truth table

for transparent gain mode.

Table 3.1 - Truth table for transparent gain mode.

| A1 | A0 | Gain
-VS | Low | Low | 1
-VS | Low | High | 2
-VS | High | Low | 5
-VS | High | High | 10
In the latched gain mode the gain is set using | as a latch. The voltages on A0 and
A1 are read on the downward edge of the | signal as it transitions from logic high to logic low.

This latches in the logic levels on A0 and A1, resulting in a gain change. The advantage of the

latched gain mode is that multiple devices can share A0 and A1 as single data bus and use the

signal as a latch, which reduces the amount of pins necessary in a microcontroller.

The truth table for the latched gain mode is presented in Table 3.2. The timing diagram

for the latched gain mode is presented in Fig. 3.8 and the digital timing specifications are listed

in Table 3.3.

Table 3.2 - Truth table for latched gain mode.

| A1 | A0 | Gain
High to Low | Low | Low | Change to 1
High to Low | Low | High | Change to 2
High to Low | High | Low | Change to 5
High to Low | High | High | Change to 10
Low to Low | X | X | No change
Low to High | X | X | No change
High to High | X | X | No change

Fig. 3.8 - Timing diagram for latched gain mode (taken from [15]).

Table 3.3 - Digital timing specifications for latched gain mode.

Parameter | Description | Value (ns)
tSU | Minimum setup time before the downward edge of | 20
tHD | Minimum hold time after the downward edge of | 10
| Minimum duration that can be held low | 20
| Minimum duration that can be held high | 40

For this work the chosen gain selection mode was the latched gain mode, because the

transparent gain mode has the problem that any noise present in the digital inputs of the

amplifier (A0 and A1) could cause an undesired gain change.

The PGIAs are represented in square 2 in the schematic from Fig. C.1 in appendix C.

## 3.5– Analog to Digital Converters

An ADC is a device capable of converting an analog input voltage in a digital word,

composed by a sequence of 0s and 1s. The maximum length of the digital output word

corresponds to the number of bits of the converter.

At first, the ADCs used for the development of the work were the ones included in the

dsPIC, which have a 12-bit resolution and are capable of conversion speeds up to 500 kS/s.

This was done in order to gain experience with the acquisition of signals and to develop an

algorithm capable of transmitting the acquired samples from the dsPIC to the PC for viewing

purposes, so it would be possible to debug any possible errors with the signal processing.

After this step was complete, the external ADCs could be used. These external ADCs

are the AD7980 from Analog Devices. The AD7980 is a successive approximation converter

with 16-bit resolution and conversion speeds up to 1 MS/s.

The AD7980 is compatible with Serial Peripheral Interface (SPI) and also features the

ability to daisy-chain several ADCs on a single data bus.

In this work, the two ADCs used were daisy-chained as represented in Fig. 3.9. The

ADCs operate in what is referred as the chain mode without busy indicator [16].

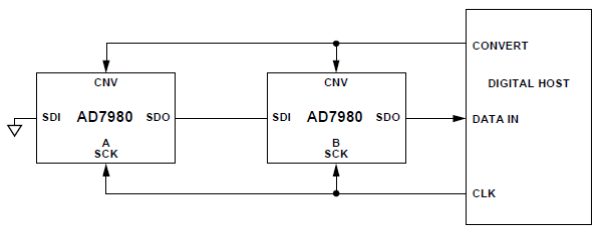
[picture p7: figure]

Fig. 3.9 - Simplified connection diagram of the two ADCs (taken from [16]).

In this mode, when SDI and CNV are low, SDO is driven low. With SCK low, a rising

edge on CNV initiates a conversion, selects the chain mode, and disables the busy indicator. In

this mode, CNV is held high during the conversion phase and the subsequent data read back.

When the conversion is complete, the ADC outputs the MSB onto SDO and the AD7980 enters

the acquisition phase and powers down. The remaining data bits stored in the internal shift

register are clocked by subsequent SCK falling edges. Each ADC in the chain outputs its data

MSB first, and 16 × 2 clocks are required to read back the 2 ADCs. The timing diagram for this

mode of operation can be seen in the ADC’s data sheet [16].

The sampling frequency of the two external ADCs is controlled by the dsPIC through the

SPI interface. In order to be possible to use the ADCs maximum conversion speed of 1 MS/s

and read the samples of both ADCs (32 bits), it would be necessary an SPI module with at least

an operating frequency of 32 MHz, however at the dsPIC’s maximum throughput, 40 MIPS, the

SPI module can only operate at a maximum frequency of 10 MHz, and so the maximum

sampling frequency possible for this work was greatly reduced. It can attain the maximum value

of 178 kS/s.

For the purposes of this thesis it is necessary to acquire bipolar sinusoidal signals,

which means it would be necessary a negative and a positive voltage reference for the ADC,

but the AD7980 only accepts positive voltage references (as well as ground), and so it is

necessary to do some signal conditioning in order to properly acquire the required signals. It

was decided to use a circuit which adds a DC offset to the signal to acquire, enabling it to be

between the voltage references of the ADC, thus removing the need for a negative voltage

reference for the ADC. A differential amplifier circuit which is represented in Fig. 3.10 was used.

This circuit is connected between the programmable gain instrumentation amplifier, which

amplifies the signal to acquire, and the ADC input.

The operational amplifier used in the circuit from Fig. 3.10 was the OP484 from Analog

Devices, which was the same kind used in the circuit from Fig. 3.6. As stated in Section 3.3, the

closed-loop bandwidth of the amplifier is about 1 MHz, which is suitable for the frequency range

used in this work.

Fig. 3.10 - Circuit of a differential amplifier used to add a DC offset to the signal to acquire.

The output voltage of the circuit is given by

If | , then

Since all the resistors are of equal value, the output voltage is given by

From equation (3.10) it is evident that the signal to acquire (VIN) will be inverted

because of the circuit from Fig. 3.10, however since the signals from both PGIAs will be inverted

and we are only interested in the phase difference between the two signals, there is no need to

correct the inverting effect of the circuit from Fig. 3.10.

The ADCs are represented in square 3 in the schematic from Fig. C.1 in appendix C.

## 3.6– Hardware for Selecting the Reference Impedances

In order to ensure that the amplitude of the acquired signals is as close as possible to

the ADC input range, it is necessary to use different reference impedances according to the

impedance to measure. This way it is possible to maximize the use of the ADC dynamic range.

The proper reference impedance will be selected among a fixed set of impedances by using

relays. Fig. 3.11 shows the setup used for the selection of the reference impedance.

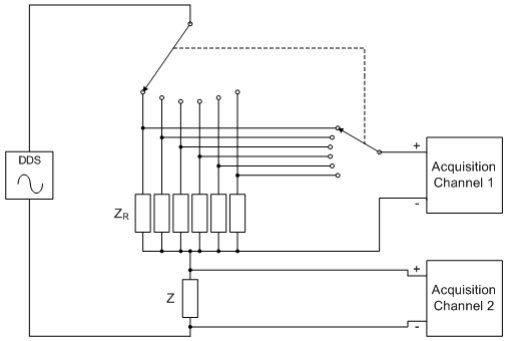
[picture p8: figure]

Fig. 3.11 - Setup for selecting the reference impedance.

In the setup from Fig. 3.11 each position of the switches corresponds to a relay. So, six

relays are used to select six reference impedances.

The selection of the reference impedance is controlled by an algorithm running in the

dsPIC.

The relays used in this work are the A5W-K from TAKAMISAWA. These relays have

two poles, a nominal voltage of 5 V and their configuration is presented in Fig. 3.12.

Fig. 3.12 - Configuration of the A5W-K relay.

In order to switch the position of the relay it is necessary a current of about 60 mA in its

coil, however the maximum current available at any pin of the dsPIC is 4 mA. So, it was

necessary to implement the circuit from Fig. 3.13 in order to control the position of the relay from

the dsPIC.

Fig. 3.13 - Circuit used to control the relays from the dsPIC.

The hardware necessary for the selection of the reference impedance is represented in

square 4 in the schematic from Fig. C.1 in appendix C.

## 3.7 – Communication Protocols

The communication protocols used in this thesis are basically three: RS-232

(Recommended Standard 232) and SPI (Serial Peripheral Interface) and USB (Universal

Synchronous Bus).

RS-232 is a standard for serial communication between devices. It supports full-duplex

operating mode and it uses two data lines: Transmit (TxD) and Receive (RxD). The binary data

uses ASCII (American Standard Code for Information Interchange) code with a word length of 7

or 8 data bits. It is capable of transmission rates up to 20000 b/s for long distances, and

921600 b/s for short distances. The transmission cable has a maximum length of approximately

15 m. Fig. 3.14 presents an example of typical RS-232 cable.

Fig. 3.14 - Example of a typical male-female RS-232 cable.

The RS-232 protocol is used to establish the communication between the dsPIC and

the PC, making it possible to send commands from the PC to the dsPIC and to send the

measurement results from the dsPIC to the PC. The transmission rate used in this work is

115200 b/s.

The hardware for obtaining the RS-232 interface is represented in square 2 in the

schematic from Fig. D.1 in appendix D.

The SPI protocol is used to communicate between the dsPIC and the ADCs, both to

control them and to transfer the acquired data from them. It will also be used to program the

DDS to generate the signal with the proper frequency to perform the measurement.

SPI is a synchronous serial interface useful for communicating with other peripheral or

microcontroller devices. It operates in master/slave mode where the master device initiates the

transmission. In this case the dsPIC will operate as the master, and the ADCs and the DDS as

the slaves. The serial interface consists of 4 pins: SDI (serial data input), SDO (serial data

output), SCK (serial clock), and SS (active low slave select). The slave uses the master’s clock,

removing the slave’s need for a precision oscillator. The SPI interface can operate using 2, 3 or

4 pins. In the 3-pin mode, SS is not used. In the 2-pin mode, neither SDO nor SS is used.

# 4 – Algorithms

This section describes the main algorithms used to effectively perform the measurement

of the unknown impedance.

The program follows the measurement procedure presented in the flowchart shown in

Fig. 4.1

Fig. 4.1 - Flowchart representing the measurement procedure of the program.

The execution time of the acquisition will depend on the sampling frequency used. In

the case of the maximum sampling frequency (178 kS/s), it is required 11.4688 ms to acquire all

of the 2048 samples (1024 samples per channel).

## 4.1– Algorithm for Selecting the Sampling Frequency

Given the measurement frequency provided by the user, it is necessary to select the

appropriate sampling frequency to acquire the signals across the reference impedance and the

impedance under measurement.

The range of frequencies used in this work goes from 500 Hz to 200 kHz. Since the

maximum sampling frequency (FSmax) is 178 kS/s, two cases must be considered for the

acquisition of the signals: the case with no under sampling, for signals with frequencies under

FSmax/2, and the case with under sampling for signals with frequencies above FSmax/2.

According to the Nyquist Sampling Theorem a signal must be acquired at a rate of at

least twice the signal’s maximum frequency (no under sampling), otherwise aliasing will occur

and the acquired signal will present an apparent frequency (under sampling). In other words,

the signal’s frequency must not exceed half of the sampling frequency (FS/2). Fig. 4.2 shows

what happens to the acquired signal’s spectrum in both cases.

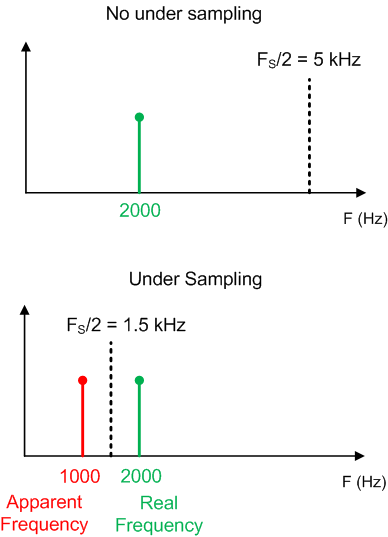
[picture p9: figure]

Fig. 4.2 - Behavior of an acquired signal spectrum in the case of no under sampling and in the case of under sampling.

In the case of under sampling, the real frequency of the signal can be retrieved from the

apparent frequency. If the real frequency is known with an uncertainty of FS/4, which is the case

of this work since the measurement frequency is selected by the user, we can determine the

number of folds of the spectrum by where Fest is the estimative of the real frequency.

If m is odd, then

If m is pair, then

where Freal is the real frequency and Fapparent is the apparent frequency of the acquired signal.

The flowchart from Fig. 4.3 describes the procedure to choose the sampling frequency.

F is the measurement frequency, FS is the selected sampling frequency, NP is the number of

periods to acquire, N is the number of samples of each acquired signal, mreal is the number of

full folds of the signal spectrum and mideal is the desired number of folds of the signal spectrum.

The mideal value is chosen in a way that, in the case of under sampling, the acquired signal’s

frequency (apparent) will be at the middle of the spectrum, which corresponds to the best case.

Fig. 4.3 - Flowchart of the algorithm used to choose the sampling frequency.

## 4.2– FFT and IpDFT Algorithms

In order to use the sine fitting algorithms it is necessary to know the frequency of the

acquired signal. To obtain the best estimative of the parameters from the sine fitting algorithms

and to reduce the number of iterations of the seven parameter sine fitting algorithm, it is

essential to have the best estimative possible of the signal’s frequency. So, it was decided to

use the FFT (Fast Fourier Transform) and IpDFT (Interpolated Discrete Fourier Transform)

algorithm [17].

The FFT algorithm is used to translate the time domain samples of the signal into the

frequency domain, thus obtaining the spectrum of the signal. Each sample in the frequency

domain is a complex number composed by a real and imaginary part.

Given the spectrum of the signal, it is possible to use the IpDFT algorithm to accurately

determine the frequency of the signal. The algorithm searches for the maximum element in the

spectrum, X(L), and its largest neighbor, X(L+1), where L is the index of the maximum element

in the array containing the frequency domain samples and L+1 the index of its largest neighbor.

0 < L < N, where N is the number of samples in the array. Given that,

then

with

where

The frequency of the signal is given by

where | is the frequency resolution of the spectrum.
| The FFT algorithm used consumes a great amount of memory (16434 bytes), which is

necessary to hold the frequency domain samples, and takes a considerable amount of time to

execute, 10.3662 ms. For this reason the execution time of the program is greatly affected,

slowing down the measurement procedure.

| The IpDFT algorithm only requires 64 bytes of memory and executes in 566.4 μs.

## 4.3– Three-Parameter Sine-Fitting Algorithm

As described in Section 2.2, the three-parameter sine-fitting algorithm is a non-iterative

algorithm that, with the knowledge of the frequency, estimates the amplitude, the phase and the

DC component of the acquired sine signal.

The acquired sine signals can be represented by

or by

where | is the amplitude, | is the phase and | is the DC component of the signal.

The parameters in (4.11) are related to those in (4.12) by

and

The | function is a variation of the | function. It takes into account the signs

of both vector components ( and ), and places the angle in the correct quadrant considering

all four quadrants. The function produces results in the range | , which can be mapped to
by adding | to negative results. The | function does not have the problem that the
function has for angles of | and | , because it would be necessary an infinite value
for the | function to produce such angles.

The estimated parameter vector is

which is given by where is the sample vector

and

N is the number of samples acquired, and | is the pseudo inverse matrix of | .

In this work, the number of samples acquired for each channel was 1024. The algorithm

takes 5.0652 ms to run and it doesn’t require much data memory to be executed (160 bytes).

The algorithm was used to make an initial estimative of the impedance under

measurement, with an initial acquisition, in order to choose the reference impedance that best

matches the magnitude of the unknown impedance. This algorithm is also used to obtain the

initial estimative for the parameters of the seven-parameter sine fitting algorithm, by using the

samples from a second and final acquisition.

The flowchart presented in Fig. 4.4 describes the execution of the algorithm.

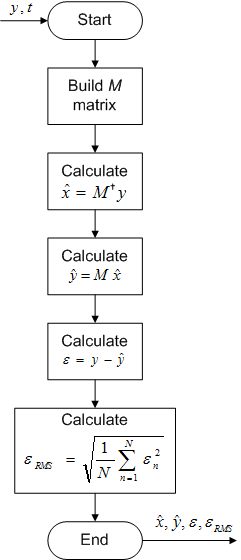
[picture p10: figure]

Fig. 4.4 - Flowchart of the three-parameter sine-fiting algorithm.

In the flowchart of Fig. 4.4 | represents the estimative of the samples, calculated based
on the estimated parameters | , | are the errors between the acquired samples and the
estimated samples and | is the total root mean square error.

## 4.4– Selection of the Reference Impedance and the PGIAs Gains

One function of this algorithm is to select the appropriate reference impedance to be

used in the measurement. The algorithm will select the reference impedance that best matches

the magnitude of the impedance under measurement. This is done in order to ensure that the

amplitude of the acquired signals is as close as possible to the ADC input range. This way it is

possible to maximize the use of the ADC dynamic range.

In order to choose the proper reference impedance, it is necessary to perform an initial

acquisition and estimate the amplitude of the unknown impedance by resorting to the three-

parameter sine fitting algorithm. This algorithm doesn’t produce the best estimative for the

parameters of the acquired signals, however since it is only intended to choose the reference

impedance, the accuracy of these parameters will be sufficient.

Another function of this algorithm is to digitally control the gains of the PGIAs to have

the maximum voltage possible at each ADC input channel in order to obtain a better resolution of the acquired signals across the reference impedance and the impedance under

measurement.

Given the magnitude of the signals, obtained with the three-parameter sine fitting

algorithm, the algorithm determines whether it is possible or not to increase the gains of each

amplifier and if so how much. The gains are set according to the values admitted by the

amplifiers and in a way that does not exceed the input range of the ADCs.

Once the correct reference impedance has been chosen and the gains of the amplifiers

are set, the actual measurement of the unknown impedance can take place.

The algorithm is divided into three steps: the selection of the reference impedance, the

estimation of the signals across the impedance under measurement and the reference

impedance after the correct reference impedance has been chosen, and the selection of the

gains of the PGIAs.

The flowchart from Fig. 4.5 describes the steps taken to choose the reference

impedance.

Fig. 4.5 - Flowchart for the selection of the reference impedance.

In Fig. 4.5, Z_REF_index refers to the index of the array that contains the values of the

reference impedances.

The reference impedances used in this work were resistors of nominal value equal to:

120 Ω, 220 Ω, 510 Ω, 1200 Ω, 2200 Ω and 5100 Ω. These resistors have a tolerance of ±5%.

To obtain the best measurement results possible, it was necessary to characterize the

reference impedances in order to determine their real values with precision, instead of just using

their nominal values. To do so, it was used a 3522-50 LCR HiTESTER from HIOKI, to measure

the reference impedances in the frequency range from 100 Hz to 100 kHz with 100 Hz intervals.

Although the range of frequencies intended for this work goes from 500 Hz to 200 kHz, it was

only measured values until 100 kHz because that is the HIOKI’s device maximum measurement

frequency. The measured values of the modulus of the reference impedances are presented in

the graphics from Fig. A.1 to Fig. A.6 in appendix A.

After obtaining these values it was necessary to estimate the resistance value (R) that

best adapts to the measured values. For this purpose it was used the fminsearch function in the

MATLAB environment. The fminsearch function minimizes the errors between the measured

values and the estimated R value, thus obtaining the optimum value for R. The estimated R

values for each reference impedance are presented in Table 4.1.

Table 4.1 - Estimated R values.

Reference Impedance (Ω) | Estimated R Values (Ω) | Error
120 | 118.255608 | 1.564026 × 10⁻⁶
220 | 216.015079 | 7.630637 × 10⁻⁵
510 | 502.384931 | 2.214254 × 10⁻⁶
1200 | 1182.838493 | 4.618403 × 10⁻⁵
2200 | 2161.503298 | 3.286041 × 10⁻⁶
5100 | 5040.373694 | 3.221815 × 10⁻⁵

The value used for the phase of the reference impedances is zero.

After the reference impedance has been chosen, it is necessary to consider the circuit

from Fig. 4.6 in order to estimate the magnitudes of the signals across the reference impedance

and the impedance under measurement.

Fig. 4.6 – Simplification of the measurement circuit.

With the knowledge of the magnitude of the signal applied to the measurement circuit

(|Vin|), the magnitude of UZREF is determined by

and the magnitude of UZ is determined by

Once the magnitudes of the signals across the impedances have been estimated, it is

possible to determine the appropriate gains of the amplifiers. Note that (4.20) and (4.21) are an

approximation since it does not account for the wiring that connects the impedances. It is

however suitable for the PGIAs gain selection.

The flowchart from Fig. 4.7 describes the process to choose the gains of the amplifiers.

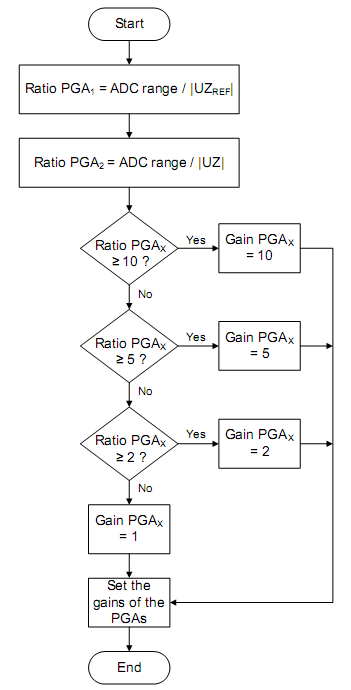
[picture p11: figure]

Fig. 4.7 - Flowchart describing how the gains of the amplifiers are chosen.

In the flowchart from Fig. 4.7, ADC range is a variable containing the range of the ADCs

used in the work, the index X is 1 in the case of PGA1, which is connected to the reference

impedance, and 2 in the case of PGA2, which is connected to the impedance under

measurement.

## 4.5– Seven-Parameter Sine-Fitting Algorithm

The seven-parameter sine-fitting algorithm was described in Section 2.2 as an iterative

algorithm which uses the acquired data from two channels with the same frequency to estimate

the amplitude, phase and DC component of both signals, plus their common frequency.

Just like in the case of the three-parameter algorithm, the sine signals of each channel

can be represented by (4.11) or by (4.12) considering the relations in (4.13) and (4.14).

Since the initial estimates of the parameters are crucial for the algorithm to converge,

these values were obtained through the three-parameter sine-fitting.

For each iteration of the seven-parameter algorithm, the estimated parameter vector is

, | and | are the estimated parameters for the signals in channel , with | = 1, 2.

is the frequency correction that updates the estimated common frequency. The

iterative process ends when the relative frequency adjustment | is below a preset
threshold, which is set to | in the case of this work. This value results from a

compromise between obtaining a frequency result with good accuracy and using the best

precision in the dsPIC.

The estimated parameter vector is given by

where is the concatenated vector with samples from both channels

and

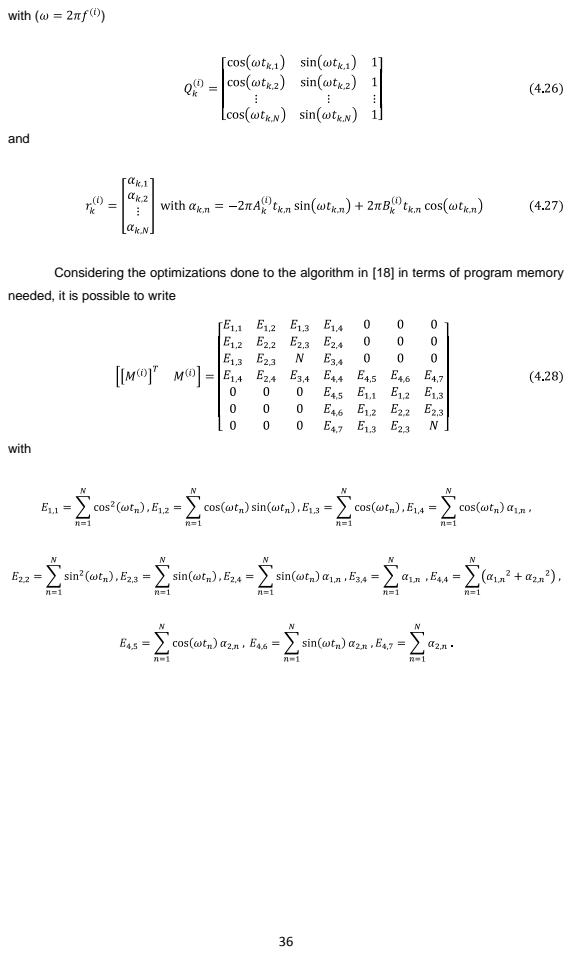
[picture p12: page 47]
with (; and; with

Considering the optimizations done to the algorithm in [18] in terms of program memory

needed, it is possible to write

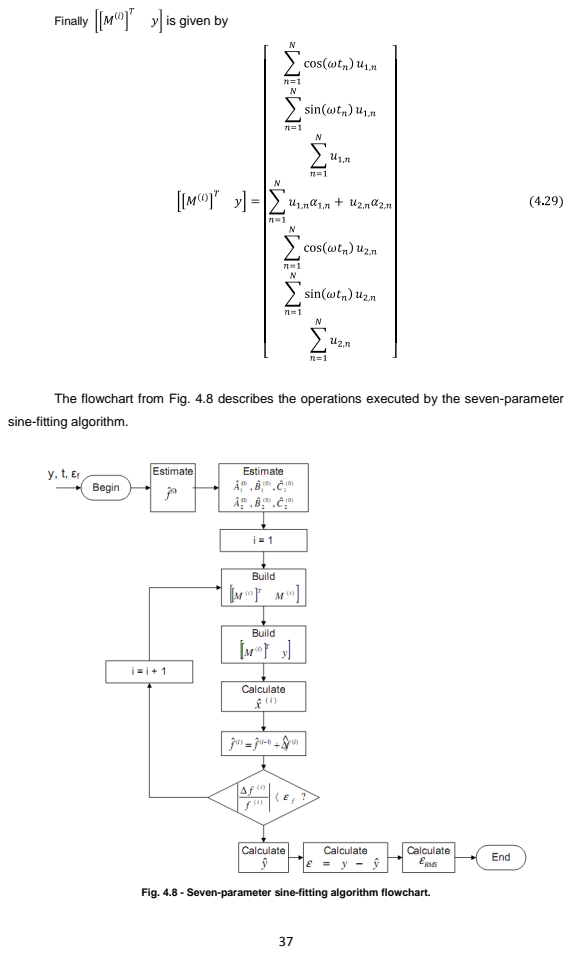
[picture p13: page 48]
Finally; is given by

The flowchart from Fig. 4.8 describes the operations executed by the seven-parameter

sine-fitting algorithm.

Fig. 4.8 - Seven-parameter sine-fitting algorithm flowchart.

In the flowchart from Fig. 4.8, | is the preset threshold for the relative frequency
adjustment, | represents the estimative of the samples, calculated based on the estimated
parameters | , are the errors between the acquired samples and the estimated samples and

is the total root mean square error.

In the seven-parameter algorithm, with the increase of noise in the acquired sine

signals, the total | error will increase which results in greater deviation of the estimated

parameters.

The implemented algorithm requires 582 bytes of memory and takes 8.7336 ms to run.

## 4.6– Reduction of Acquired Samples to the First Period

In the case of under sampling it was decided to reduce the acquired samples to the first

period of the signals. This was done to allow the user to view the acquired signals with the

correct frequency and amplitude in order to facilitate the detection of any eventual error.

Otherwise it would be extremely difficult to interpret the acquired samples.

To reduce the acquired samples to the first period one has to build an array with the

new time stamps correspondent to the first period. To do so we must consider

where | are the original time stamps, | is the period of the signal and | is the array

with the new time stamps reduced to the first period.

After obtaining the array with the new time stamps it is simply a manner of ordering the

time array, along with the samples correspondent to each time stamp.

The flowchart from Fig. 4.9 describes the execution of the algorithm.

Fig. 4.9 - Flowchart of the algorithm to reduce the samples to the first period.

# 5 – Experimental Results

In this Section the experimental results obtained with the implemented system are

presented.

Ten impedances with different amplitudes in the range from 100 Ω to 10 kΩ, and

phases in the range from -90º to 90º were tested at 1 kHz and the results are compared to

those obtained with the 3522-50 LCR HiTESTER from HIOKI.

The measurement results are presented in Table 5.1.

Table 5.1 - Measurement results obtained with the HIOKI and the implemented system.

HIOKI | Implemented System
Impedance | Modulus (Ω) | Phase (º) | Modulus (Ω) | Phase (º)
C = 32 nF | 4979,4 | -89,74 | 4989,23 | -89,72
L = 15 mH | 105,9 | 69,18 | 105,39 | 68,95
Serial RC R = 2 kΩ ; C = 47 nF | 3899,1 | -58,7 | 3932,89 | -59,02
Serial RC R = 5,6 kΩ ; C = 47 nF | 6527,7 | -31,08 | 6546,40 | -31,13
Serial RL R = 120 Ω; L = 15 mH | 184,61 | 32,07 | 183,95 | 31,83
Serial RL R = 36 Ω; L = 15 mH | 122,85 | 53,45 | 122,3 | 53,30
R = 1,8 kΩ | 1782,6 | 0 | 1790,8 | 0,0012
R = 7,5 kΩ | 7408,4 | 0 | 7454,59 | -0,041
R = 9,1 kΩ | 8957,1 | 0 | 9005,64 | -0,056
R = 10 kΩ | 9866,8 | 0 | 9923,33 | -0,027

As shown in Table 5.1, the experimental results obtained with the implemented system

are quite close to those obtained with the HIOKI, demonstrating that it is possible to implement

a low-cost impedance measurement device with comparable precision of that of sophisticated

measurement equipment.

The signals acquired by the implemented system correspondent to the impedances

measured are presented in Fig. 5.1 to Fig. 5.10.

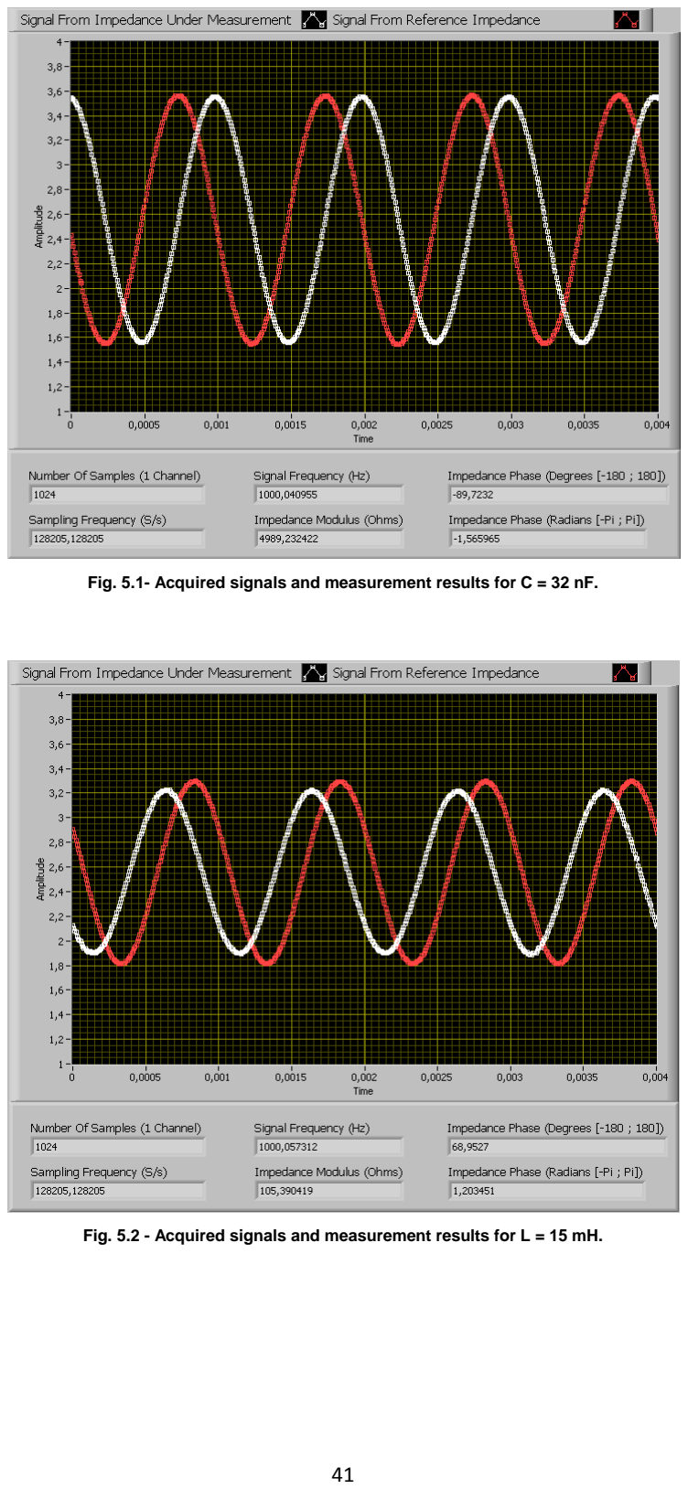
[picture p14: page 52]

Fig. 5.1- Acquired signals and measurement results for C = 32 nF.

Fig. 5.2 - Acquired signals and measurement results for L = 15 mH.

Fig. 5.3 - Acquired signals and measurement results for R = 2 kΩ, C = 47 nF.

Fig. 5.4 - Acquired signals and measurement results for R = 5.6 kΩ, C = 47 nF.

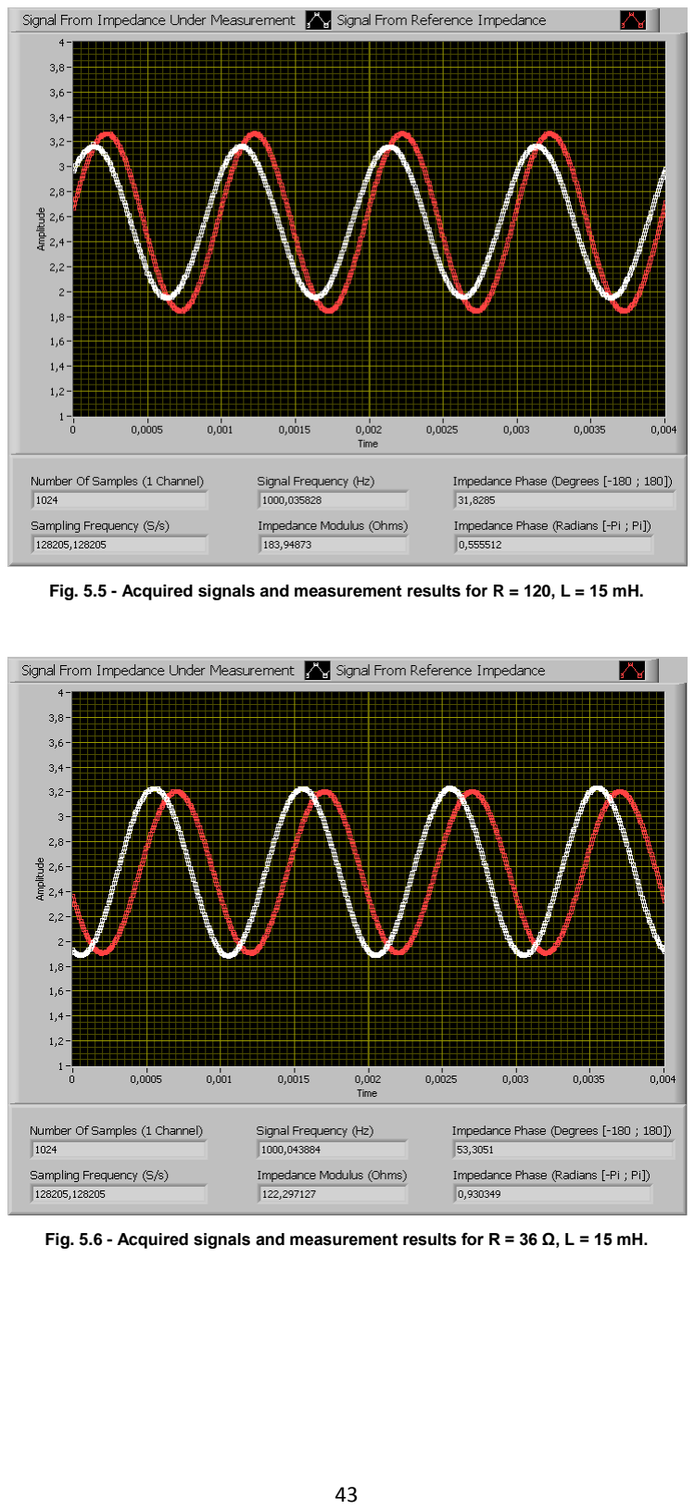
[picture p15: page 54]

Fig. 5.5 - Acquired signals and measurement results for R = 120, L = 15 mH.

Fig. 5.6 - Acquired signals and measurement results for R = 36 Ω, L = 15 mH.

Fig. 5.7 - Acquired signals and measurement results for R = 1.8 kΩ.

Fig. 5.8 - Acquired signals and measurement results for R = 7.5 kΩ.

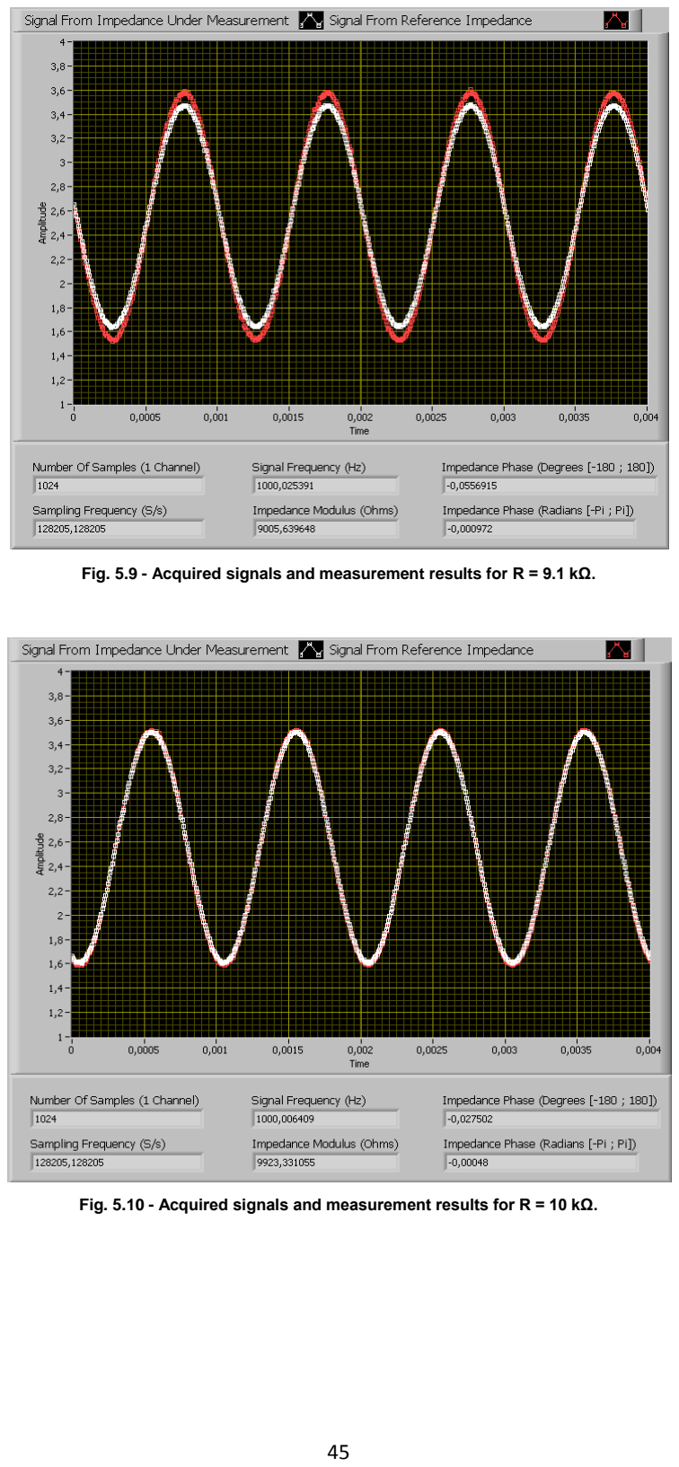
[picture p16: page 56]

Fig. 5.9 - Acquired signals and measurement results for R = 9.1 kΩ.

Fig. 5.10 - Acquired signals and measurement results for R = 10 kΩ.

Five hundred measurements of the same impedance were taken at a measurement

frequency of 1 kHz. The impedance tested was a resistor with a nominal value of 7.5 kΩ. With

these measurements it was possible to obtain the histograms of the measurement frequency

the amplitude and the phase of the impedance. It was also obtained the dispersion of the

complex value of the impedance in the Argand plane. These results are presented in Fig. 5.11

to Fig. 5.14.

Fig. 5.11 - Histogram of impedance amplitude.

The measurements regarding the impedance amplitude present a mean of 7455,68 Ω, a

standard deviation of 1,29 Ω and a relative standard deviation of 0,017 %.

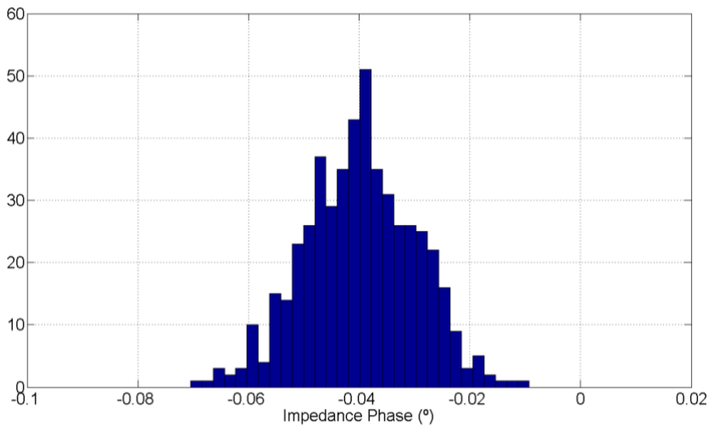
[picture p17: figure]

Fig. 5.12 - Histogram of impedance phase.

The measurements regarding the impedance phase present a mean of -0,0399 º and a

standard deviation of 0,0999 º.

Fig. 5.13 - Histogram of measurement frequency.

The measurements regarding the measurement frequency present a mean of

1000,03005 Hz, a standard deviation of 0,00664 Hz and a relative standard deviation of

0,00069 %.

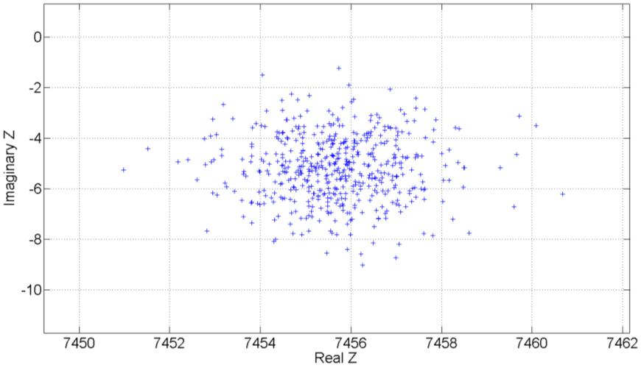
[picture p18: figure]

Fig. 5.14 - Dispersion of the complex value of the impedance in the Argand plane.

# 6 – System’s Control Software

It was implemented a control software which runs in a PC. The software acts as an

interface between the user and the device, giving its user the means to interact with the device.

This software allows the user to choose the frequency at which to perform the measurement of

the unknown impedance. Another feature of the software is the ability to communicate with the

device in order to obtain information regarding the device’s maximum operating ranges. An

important aspect of the software is the fact that it allows the user to view and interpret the

acquired samples of the measurements done.

The software was developed in the LabVIEW environment, which provides simple and

intuitive programming tools to implement even the most complex program, and also has the

capability to easily create an application that can run in a PC, even if it does not have the

LabVIEW environment installed.

The main window of the implemented software is represented in Fig. 6.1.

Fig. 6.1 - Control software main window.

Once the program is running and the desired measurement frequency has been

introduced, the user can begin the measurement of the unknown impedance by clicking the

start button.

The window of the control software has a LED which indicates the status of the

program. When the user starts the measurement procedure the LED lights up, indicating that

the PC is communicating with the device. After the measurement is complete and all of the data

has been successfully received by the PC, the LED goes off indicating that the program is

standing by and ready for the next measurement.

After the measurement results have been received by the PC, the user can choose to

save the results, along with the acquired samples of the signals across the impedances. To do

so he has only to click the save button, which results in the appearance of the window

presented in Fig. 6.2.

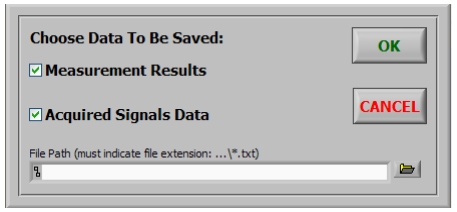
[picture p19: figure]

Fig. 6.2 - Save data program window.

In the window presented in Fig. 6.2 the user chooses the information to be saved and

the location of the file containing the data (File Path). The file is saved as a text file with the

extension txt.

The user can also use the control software to ask the device its maximum operating

ranges by clicking the ranges button. Just like during the measurement procedure, while the PC

is communicating with the device the LED remains lit until the data has not been received.

Afterwards, when the ranges of the device have been received, the LED goes off and the

program returns to the standby mode.

The ranges of the device appear in the window presented in Fig. 6.3.

Fig. 6.3 - Program window that presents the ranges of the device.

The ranges of the device correspond to: measurement frequency, impedance modulus

(|Z|) and sampling frequency.

# 7 – Conclusions

Impedance measurements have a great number of applications in different fields of

science, such as medicine, civil engineering and applications where it is necessary to

characterize sensor outputs, thus making it an important field of investigation.

Given the high cost of sophisticated equipment dedicated to impedance measurement,

it is important to develop new and cheaper ways to make the same type of measurements at a

more reduced cost.

The measurement setup proposed in this work is an attempt to do just that. It uses a

number of low cost equipment, which by operating together can produce results with

comparable accuracy to those obtained with dedicated measurement equipment. This is

possible because of the great processing capability of the processing unit used, the dsPIC,

combined with the powerful signal processing techniques applied, the three-parameter sine

fitting algorithm and the seven-parameter sine fitting algorithm.

The implemented system facilitates the interaction with its user, since it is possible to

connect it to a PC, through a RS-232 connection, to receive commands from the user and allow

him to monitor the device and save the results of the measurements done.

The system implemented in this thesis operates in a wide frequency range, 500 Hz to

200 kHz, and is capable of measuring impedances in the amplitude range from 100 Ω to 10 kΩ.

To operate in this frequency range it was necessary to apply under sampling techniques

because of the constraints imposed by the dsPIC in terms of maximum sampling frequency.

The experimental results produced in this work were compared with a commercially

available device, the 3522-50 LCR HiTESTER from HIOKI, by measuring ten different

impedances in the amplitude range from 100 Ω to 10 kΩ and in phase range from -90º to 90º at

a measurement frequency of 1 kHz. Given the experimental results presented, it was

demonstrated that it is possible to implement a low-cost device operating at a wide frequency

range, but still with measurement precision comparable to that of sophisticated high-cost

dedicated impedance measurement systems.

# 8 – Future Work

In order to improve the work presented in this thesis it is proposed a few research

directions.

One of the proposed modifications to be done regards the upgrade of the device to act

as a stand-alone system without the need of a PC to control it. This involves the implementation

of a keypad to give the user the ability to control the device independently. This way the user

would have the choice to control the device without using the PC.

Another important modification is the upgrade of the processing unit from a dsPIC to a

DSP. This would improve the processing capabilities of the device in terms of throughput and

available data memory, thus allowing the device to perform the estimation of the unknown

impedance in less time. The increase in data memory would allow the acquisition of more

samples, and so a better resolution of the acquired signals.

It would also be interesting to give the device the ability to measure the impedances at

different frequencies in a single acquisition. To do so it is suggested the study of multi-harmonic

signals to stimulate the measurement circuit.

# 9 – References

[1] The Impedance Measurement Handbook – A Guide to Measurement Technologies and

Techniques, Agilent Technologies Co., 2000.

[2] Olumuyiwa T. Ogunnika, Michael Scharfstein, Roshni C. Cooper, Hongshen Ma, Joel L.

Dawson and Seward B. Rutkove, “A Handheld Electrical Impedance Myography Probe

for the Assessment of Neuromuscular Disease”, 30th Annual International IEEE EMBS

Conference, Vancouver, British Columbia, Canada, August 20-24, 2008.

[3] Michael Scharfstein, “A Reconfigurable Electrode Array for Use in Rotational Electrical

Impedance Myography”, Thesis for the Degree of Master of Engineering in Electrical

Engineering and Computer Science, Massachusetts Institute of Technology, September

2007.

[4] M. Mancio, J. Zhang and P.J.M. Monteiro, “Nondestructive surface measurement of

corrosion of reinforcing steel in concrete”, Canadian Civil Engineer, v. 21, no. 2, pp. 12-

14, May 2004.

[5] Agilent | 4294A | Precision | Impedance | Analyzer, | Data | Sheet, | available | at

www.agilent.com April 2008.

[6] Agilent 4287A RF LCR Meter 1 MHz - 3 GHz, Data Sheet, available at www.agilent.com

October 2004.

[7] Agilent 4395A Network/Spectrum/Impedance Analyzer, Data Sheet, available at

www.agilent.com February 2008.

[8] IEEE Std. 1057-1994, Standard for Digitizing Waveform Records, The Institute of

Electrical and Electronics Engineers, New York, December 1994.

[9] Pedro M. Ramos and A. Cruz Serra, “A new sine-fitting algorithm for accurate amplitude

and phase measurements in two channel acquisition systems”, Measurement, Elsevier,

Vol. 41, No. 2, pp. 135-143, Feb. 2008.

[10]P. Händel, “Parameter estimation employing a dual-channel sine-wave model under a

gaussian assumption,” IEEE Trans. Instr. Meas., vol. 57, no. 8, pp. 1661–1669, Aug.

2008.

[11]Pedro M. Ramos, Fernando M. Janeiro, Mouhaydine Tlemçani and A. Cruz Serra,

“Recent Developments on Impedance Measurements With DSP-Based Ellipse-Fitting

Algorithms”, IEEE Transactions on Instrumentation and Measurement, vol. 58, no. 5,

May 2009.

[12]R. Halír and J. Flusser, “Numerically stable direct least squares fitting of ellipses,” in

Proc. WSCG, Feb. 1998, pp. 125–132.

[13] M. Fonseca da Silva, Pedro M. Ramos, A. Cruz Serra, “Impedance Measurement Using

Sine Fitting Algorithms”, 12th IMEKO TC4 International Symposium Electrical

Measurements and Instrumentation, September 25−27, 2002.

[14]Neil P. Albaugh, The Instrumentation Amplifier Handbook, Burr-Brown Corporation.

[15]Analog Devices AD8250 PGA, Data Sheet, available at www.analog.com June 2009.

[16]Analog Devices AD7980 ADC, Data Sheet, available at www.analog.com June 2009.

[17]Tamás Zoltán Bilau, Tamás Megyeri, Attila Sárhegyi, János Márkus, István Kollár, “Four

Parameter Fitting Of Sine Wave Testing Result: Iteration and Convergence”, Computer

Standards and Interfaces, Vol. 26, pp. 51-56, 2004.

[18]Pedro M. Ramos, Fernando M. Janeiro, Tomáš Radil, “Comparison of Impedance

Measurements in a DSP using Ellipse-fit and Seven-Parameter Sine-fit Algorithms”,

Elsevier Editorial System(tm) for Measurement, 2009.

# A – Reference Impedance Measurement Results

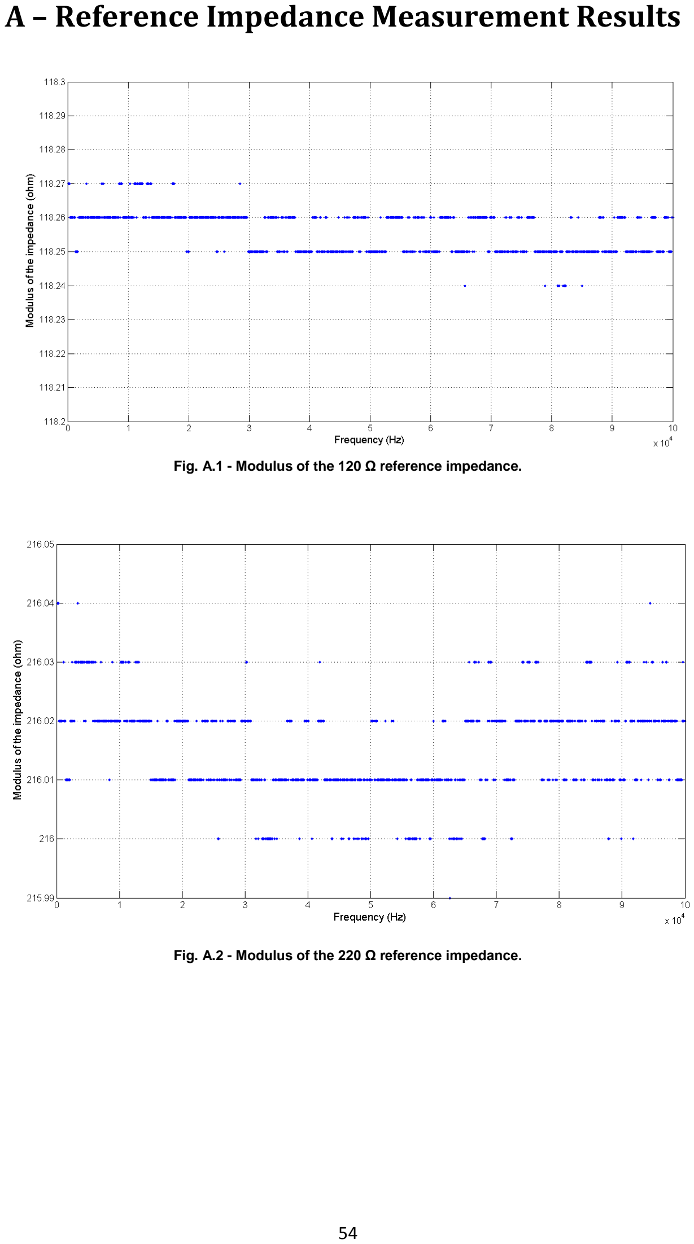
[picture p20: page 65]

Fig. A.1 - Modulus of the 120 Ω reference impedance.

Fig. A.2 - Modulus of the 220 Ω reference impedance.

Fig. A.3 - Modulus of the 510 Ω reference impedance.

Fig. A.4 - Modulus of the 1200 Ω reference impedance.

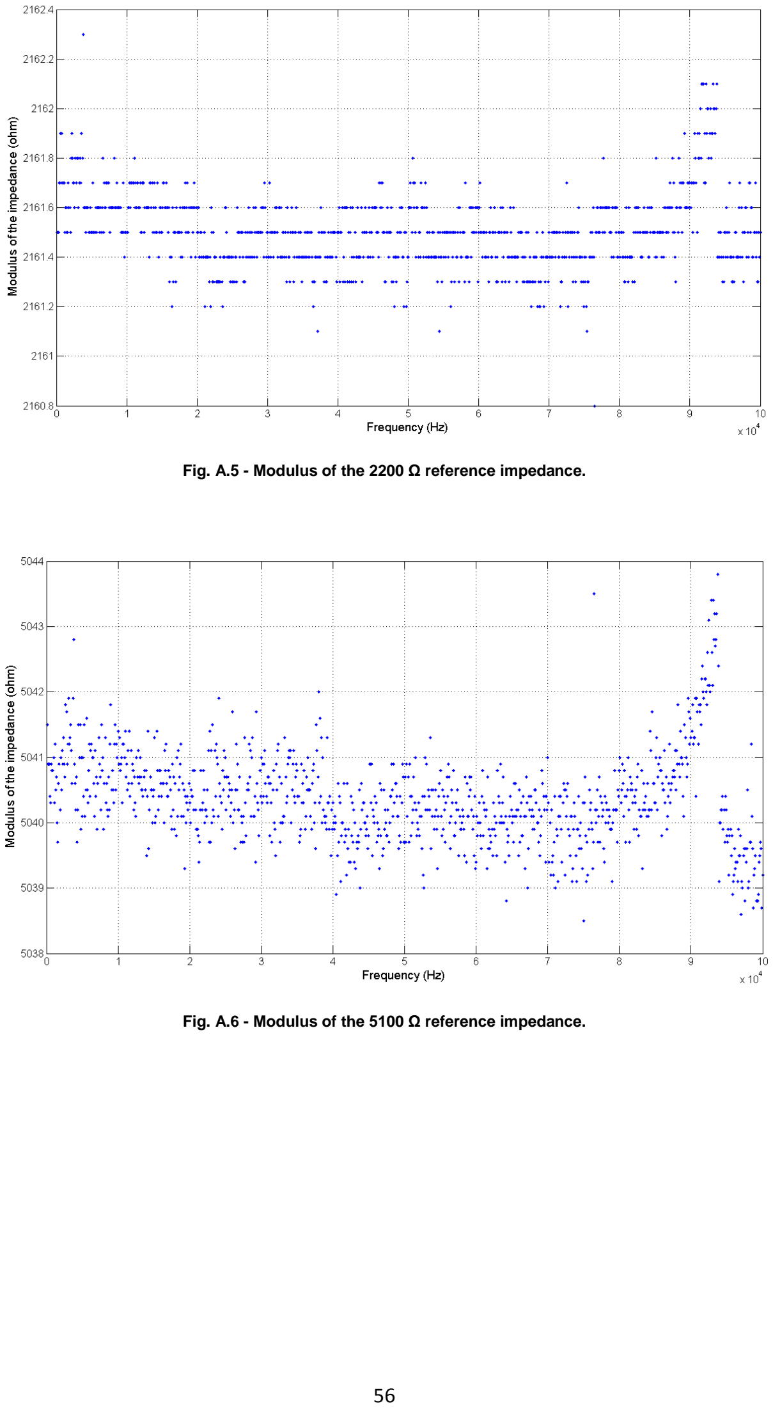
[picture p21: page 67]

Fig. A.5 - Modulus of the 2200 Ω reference impedance.

Fig. A.6 - Modulus of the 5100 Ω reference impedance.

# B – Encoding of Acquired Data to Transmit to PC

Upon the completion of the measurement procedure of the unknown impedance, it is

necessary to transmit the measurement results to the computer. The acquired samples of the

signals across the impedances must also be sent to the computer.

Given the amount of data to be sent to the computer, 1024 samples per channel with 16

bits per sample, it was necessary to implement an algorithm to encode the acquired data so it

could be sent to the computer in an efficient way, in order to reduce the necessary time for the

data transmission.

The acquired data is in the unsigned integer format. In order to transmit the data to the

computer the data has to be converted into the ASCII (American Standard Code for Information

Interchange) format. Each character of the ASCII table is represented in 7 bits, but each sample

is represented in 16 bits, so, it is necessary to break each sample into “pieces”, three to be

exact: two “pieces” of 6 bits and one of 4 bits. So, for each sample it is necessary to transmit

three characters. Two characters corresponding to two integers of 6 bits and one character

corresponding to an integer of 4 bits. Fig. B.1 illustrates the process for an ADC sample of

65535.

Fig. B.1 - Encoding of an ADC sample.

Although each ASCII character can be represented in 7 bits, it was decided to use a

maximum of 6 bits to represent each part of the sample, because before each integer is

converted into the ASCII format, each integer is added a value of 48 to avoid using any of the

special characters of the ASCII table, some examples are: STX (Start Of Text), ACK

(Acknowledge) and ESC (Escape).

The conversion from the integer values to ASCII characters are done by assigning the

integer values to char type variables.

The flowchart from Fig. B.2 describes the execution of the algorithm.

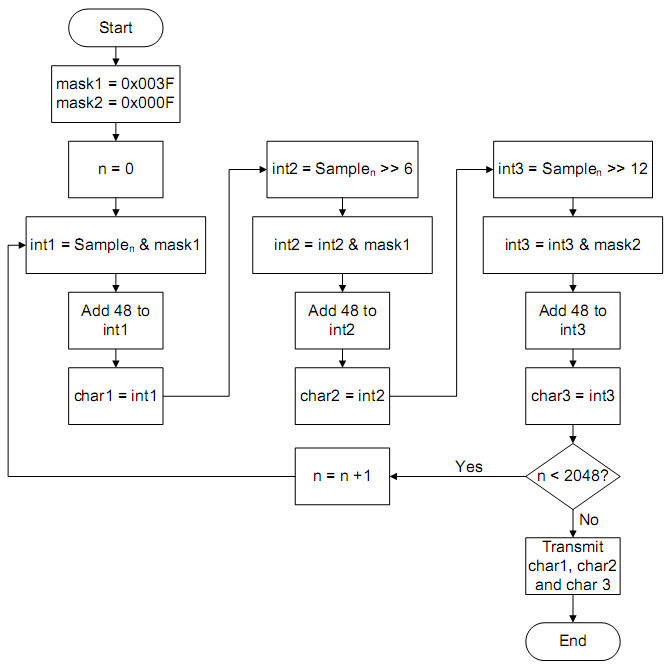
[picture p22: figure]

Fig. B.2 - Flowchart describing the encoding of the acquired samples.

In the computer end, it is necessary to perform the inverse operations described, in

order to obtain the correct values of the decoded samples transmitted by the dsPIC.

# C – Schematic of the Measurement Circuit

Fig. C.1 - Schematic of the measurement circuit.

# D – Schematic of the Complete System

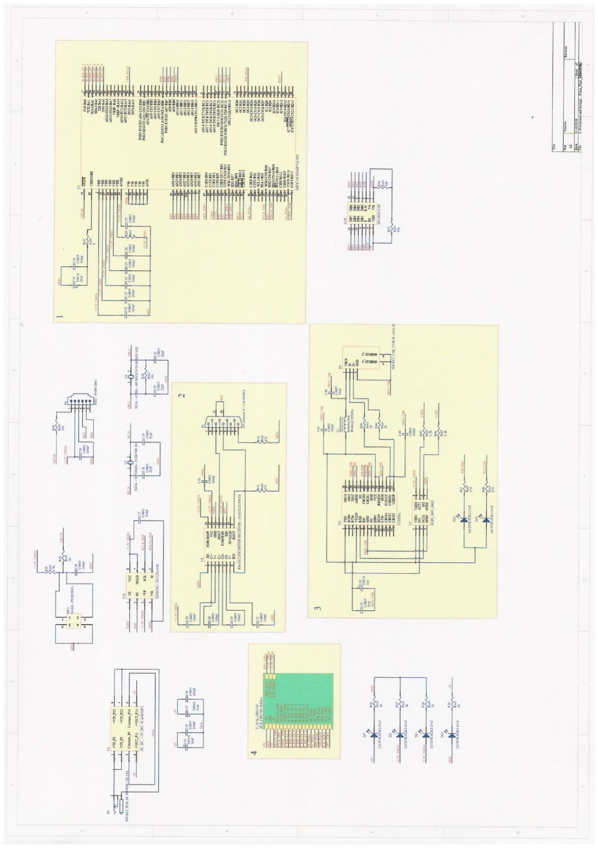
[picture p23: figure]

Fig. D.1 - Schematic of the complete system. Square 3 represents the hardware for the USB interface. The symbol in square 4 represents the circuit from Fig. C.1 in appendix C.

# E – PCB of the Complete System

The entire system was implemented in a PCB which includes the processing unit and

the digitizing channels.

The layout of the board is presented in Fig. E.1 (top layer) and Fig. E.2 (bottom layer).

Since the board is still in production, it was not possible to test it in order to obtain

experimental results regarding the measurement of impedances, so only the layout of the board

is presented in this appendix.

Fig. E.1 - Layout of the PCB of the entire system - top layer.

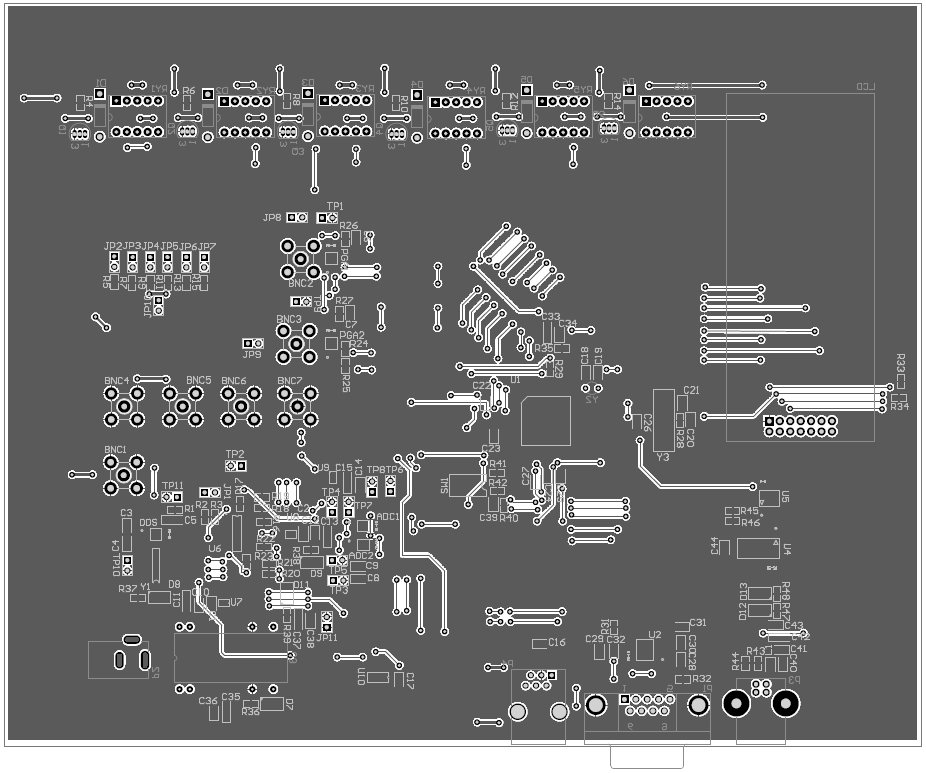
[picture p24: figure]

Fig. E.2 - Layout of the PCB of the entire system - bottom layer.

Although the board includes the USB interface given by the FT232RL USB to UART device, this feature was not tested yet because, as stated before the board is still in production.

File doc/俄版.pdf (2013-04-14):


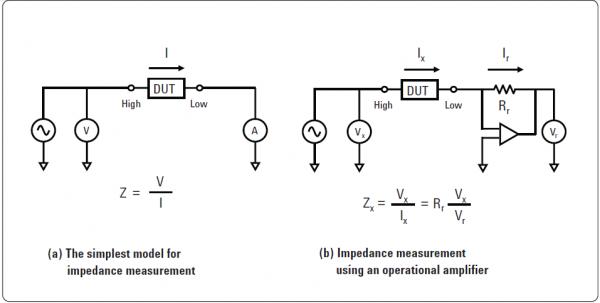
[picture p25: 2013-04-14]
doc/lcr.jpg

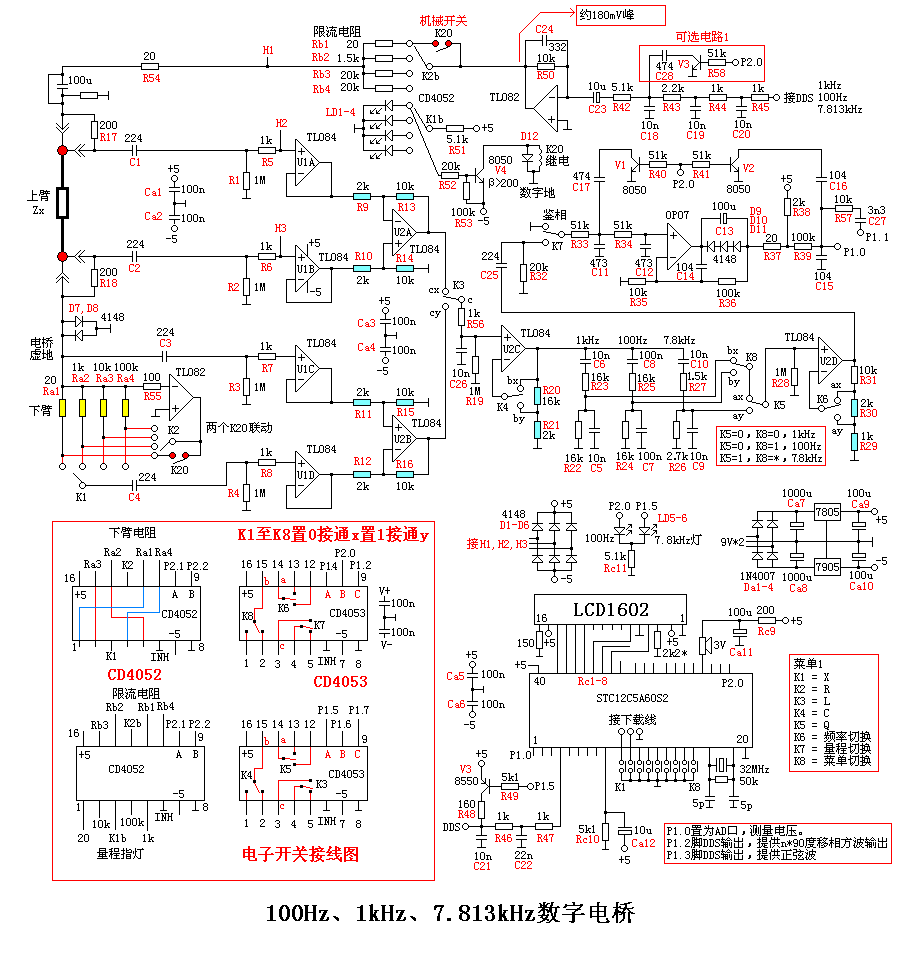
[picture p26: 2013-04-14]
myLCR.PNG

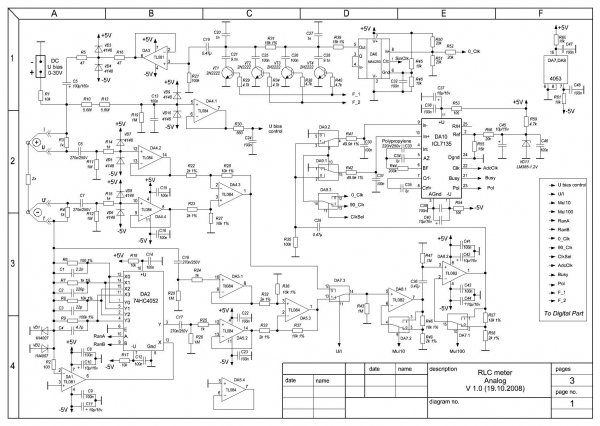
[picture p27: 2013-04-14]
doc/lrc_circuit.jpg

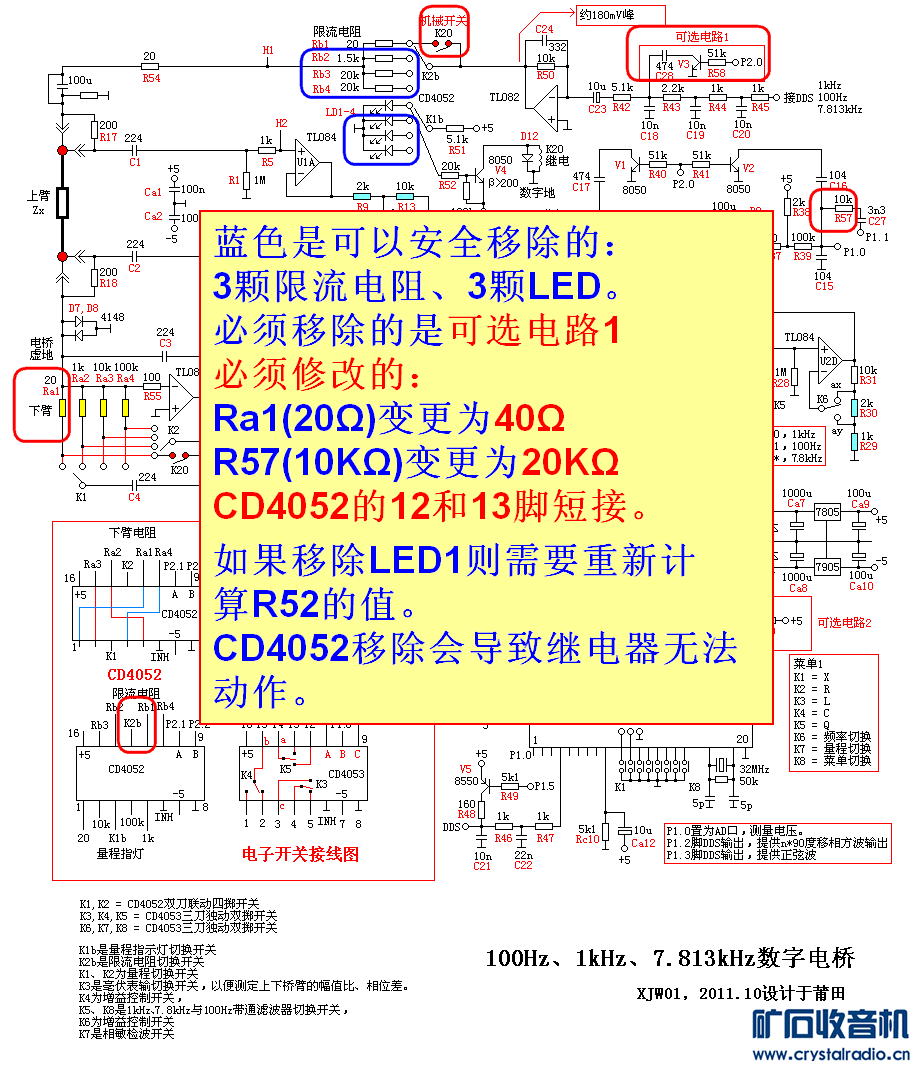
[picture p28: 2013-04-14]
myLCR2to3.png

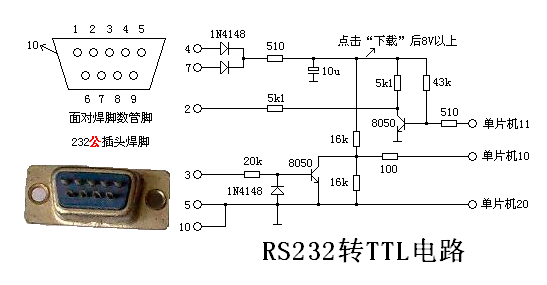
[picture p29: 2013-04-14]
RS232-TTL.PNG

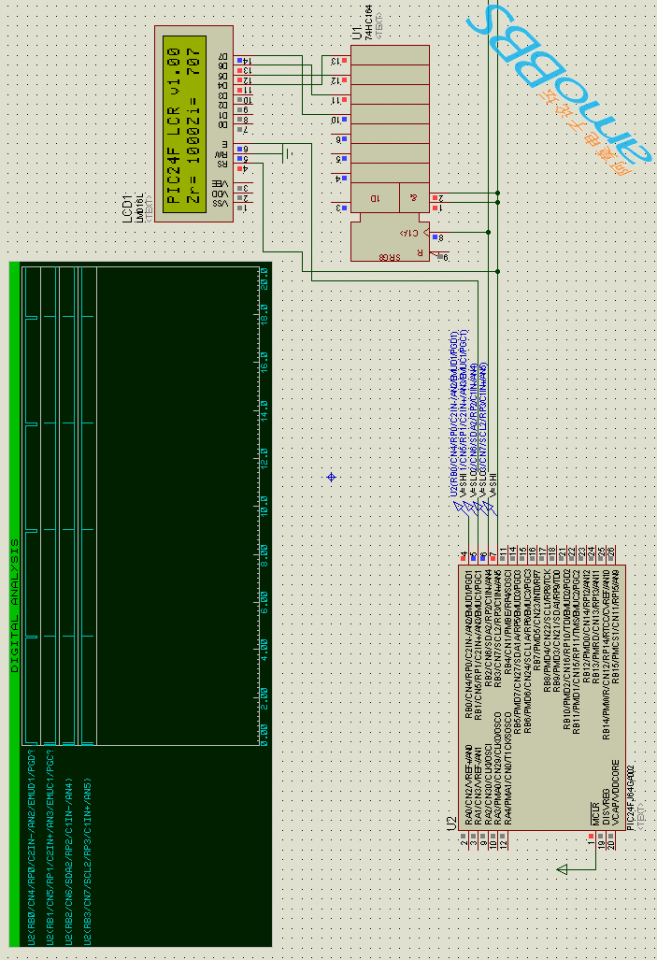
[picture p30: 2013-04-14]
doc/pic24f_lcr.png

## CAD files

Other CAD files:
STVD/Cosmic/stm8af62ax.stp
STVD/Raisonance/stm8s003.stp
STVD/Cosmic/stm8s208.stp
STVD/Raisonance/stm8s207.stp
STVD/Cosmic/stm8af626x.stp
STVD/Raisonance/stm8af626x.stp
STVD/Cosmic/stm8s003.stp
STVD/Raisonance/stm8s103.stp
STVD/Cosmic/stm8s903.stp
STVD/Raisonance/stm8af52ax.stp
STVD/Cosmic/stm8s105.stp
STVD/Raisonance/stm8s903.stp
STVD/Cosmic/stm8s005.stp
STVD/Raisonance/stm8s208.stp
STVD/Cosmic/stm8s207.stp
STVD/Raisonance/stm8s007.stp
STVD/Cosmic/stm8s103.stp
STVD/Raisonance/stm8af62ax.stp
STVD/Cosmic/stm8af52ax.stp
STVD/Cosmic/stm8s007.stp
STVD/Raisonance/stm8s005.stp
STVD/Raisonance/stm8s105.stp

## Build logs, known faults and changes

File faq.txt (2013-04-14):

1、电感测量误差
很多带磁芯的电感，在不同电压下测得的电感量是不相同的。空芯线圈，高频低导磁率磁芯，这类线圈电感量与电压相关性较小。因此，这类线圈才能用于精度对比测试。
2、晶振不起振
25M以上的晶振，大多是泛音晶振。因此，我们买到的32MHz晶振，一般是三次泛音晶振。当电路没有匹配好，晶振可能振于基音，此时频率只有预期值的1/3。在下载程序时，ISP程序会提示当前晶振的振荡频率。
当晶振振荡于基音，电路无法正常工作，单片机速度降为1/3，响应迟钝，按下键时要按住较长时间才响应，开机时须等待8秒钟左右（正常3秒钟左右），1k欧档指示才会亮起来。要让它谐振在32MHz，先给晶振加上负载电容，即晶振两端分别对地接上5pF电容。然后在晶振两端并联合适的电阻，就会谐振在32MHz
有负载电容时，谐振时， 晶振表现为感抗，可以把晶振看作电感器L，它与负载电容谐振。之后，并联一个电阻，LC回路Q值下降。负载电容不变时，低频Q值下升快，因此基音更容易失振，使电路振于泛音。负载电容也不要超过5pF，以免负载过重，电路不起振。
用5K、10k、20k、50k、100k……电阻试验，我得到的结果是：5k不起振，10k,20k,50k振于32MHz，100k及以上振于32/3=10.7MHz
显然，取20k电阻并联于晶振最好。不同厂家，不同批次的晶振，此电路中采用的电阻是不同的。要自己试验
气温变化，也可能造成晶振工作频率不正确或停振。这可能是电阻没有匹配好或晶振有问题。如果停振，应加大电阻，如果振于基音，应减小电阻。如果通过调整电阻还是无法正常工作，则需要更换晶振。
3、如何把220pF的电容精确测量到0.1pF
由于表笔轻微移动，就可能造成表笔电容变化0.1pF，最终引起电容测量误差。
准备一个排针插座，被测电容焊在排针上。先用表笔夹住插座，测出开路电容。然后插入被测电容进行测量。两次测值之差就是电容的真值。测量期间，注意保持表笔间的距离不变。
4、如何防止EEPROM数据丢失。
用户数据flash EEPROM数据易丢失。经实验表明，数据丢失发生在异常上电、断电过程，如电源插头接触不良引起电压不稳时，容易造成数据丢失，而且一般是第一扇区数据丢失。因此，建议加一个电源开关，这样可以使上电、断电干脆、可靠。程序中应把数据写入第二或第三扇区，可以大大减小数据丢失的可能性，早期版本程序把数据写入第一扇区，容易引起数据丢失，因此请使用最新版的程序。最新程序还做了第二重保护，即EEPROM触发时，加入了触发条件，当电源易常时，内存数据丢失，触发条件将不满足，EEPROM被保护。
5、如何筛选R9——R16电阻
R9——R12四个2k电阻请使用阻值相同的。先筛选出4个相差在0.3%以内电阻。然后在这四个电阻中，取两个相差仅0.1%以内的电阻做为R9、R12，四个电阻温漂应小于50ppm/K且温漂一致。
R9——R12四个10k电阻请使用阻值相同的。先筛选出4个相差在0.3%以内电阻。然后在这四个电阻中，取两个相差仅0.1%以内的电阻做为R13、R16，四个电阻温漂应小于50ppm/K且温漂一致。
  Ra1至Ra4建议使用误差小于0.3%的电阻，温漂小于25ppm/K
  R20、R21的比值应为8:1，比值精度应筛选到0.3%以内，温漂小于25ppm/K
  R30、R29的比值应为2:1，比值精度应筛选到0.3%以内，温漂小于25ppm/K
6、如何测量电阻的温漂
本表要求使用温度系数优于50ppm/度的电阻，强烈建议使用优于25ppm/度的电阻。
在冬天，找个气温10至20度天气。用小温度计测出手指与气温之间的温差T。
然后测出电阻的阻值。用手指隔着塑料膜捏住电阻进行加热，测得电阻阻值的相对变化量dR。那么温度系数为dR/T
现在买到的2至4分钱的金属膜电阻，温度系数一般小于25ppm/度，达到50ppm/度的是少数，一般是小于10ppm/度。
如果手指温度不够，可以用热水烫手5分钟，活血后再做实验，建议穿上保暖衣服。
一整排电阻中，大部分温度系数差不多，但也可能出现个别特别差的。如，测得10个，可能9个优于10ppm/度，偏偏出现一个50ppm/度的。
如果觉得筛选与测量麻烦，建议直接购买0.1%的电阻。
7、感觉测电解电容不准
电解电容、瓷片电容、独石电容，实测值与标称值相差10%甚至50%都有可能的。因为，这些电容本身不是精密电容。涤纶电容、CBB电容，测值与标称值一般相差在10%以内。好一点的电容，一般相差2%以内。
电解电容的容量，用100Hz准确测定，二线法即可。1kHz容量会减小的。7.8kHz一般要用四线法才能准确测出容量。随频率升高，容量减小越多，说明电容频响不好。
8、电容精度有必要校准吗？
  不需要校准的。电阻校准了电容测量自动准确。验证电阻精度，至少要使用四位半的表，不能使用2000字的三位半的表。2000字的表，精度比本表低。因为，2000字的表，测量2xx读数的电阻，误差可能高达1%，验证不了本电桥。6000字的品牌表，电阻档精度一般也是比本表差，除非更换内部分压电阻。
9、如何选择量程
被测阻抗有两个参数，分别为电抗x和电阻r，串联测量时取x、r中最大的为主参数Z（并联时取x、r中最小的为主参数Z）。量程电阻记作R
所选量程满足0.8R<Z<8R时，就是就最佳量程。
如果找不到合适量程，可以选至0.1R<Z<10R
10、何时采用四线法
测量小电阻，为了准确到1毫欧，这时要采用四线法。3欧以上，通常使用二线法即可（即头尾两个端子），记得扣除短路残余值。
采用二线法，最多准确到5毫欧，而且要尽可能排除接触不良问题。
11、表笔长度要多长
建议总长度（包括夹子）不要超过15cm
用带屏蔽的开尔文四端夹子，长度也不要太长，建议小于40cm，且采用分布电容小的屏蔽线。
12、如何开路、短路清零
表笔开路按下C键做开路清零。
表笔短路按下C键做短路清零。
如果开路清零不满意，再按C键。清零后，可能出现超大电感残余与超小电容残余显示之间跳变。切换为并联模式，允许显示小量的负电容，因此不易出现超大感的显示。
如果短路清零不满意，再按C键。清零后，可能出现超大电容残余与超小电感残余显示之间跳变。切换为串联模式，允许显示小量的负电感，因此不易出现超大容的显示。
清零前，请等显示屏到相对稳定，一般需要两三秒钟。
开路、短路清零只对当前频率及当前量程有效，如，在7.8kHz 100k欧档清零，那么切换到其它档位之后（如频率或量程变更），那么无清零效果。
按下L键或重新开机则取消清零，开路、短路清零数据同时置零。
开路、短跳清零数据在程序内部是独立的，互不影响。因此，同一档位，可以同时做开路、短路清零两项工作。
13、如何精确测量NPO小电容
首先，建议使用7.8kHz档。
其二，建议进行开路清零。要使用插座，即表笔夹上小插座后进行开路清零
其三，然后插入被测电容即可得到正确读数。插入电容前后，要保持两表笔间的相对位置不变化。
14、频率不变，切换量程后电容测值相差较多，正常吗？
  如果两个量程都满足0.1R<Z<10R，那么，对于CBB、涤纶等电容，测值应相差0.4%以内才正常。独石电容（非NPO）、瓷片电容（非NPO）切换量程，测值超过0.4%是正常的，因为他们的容量与测量电压有关。
15、校准后，零点参数Z0与Z1约75左右，而Z0小于40，正常吗？
通常，Z1、Z2、Z2较为接近，如Z0=75、Z1=75、Z2=70，说明cd4053频响好。
此例中，如果Z2=40，说明CD4053频响稍差一点，但对相位精度影响不大。如果Z2=10，可能不行，易造成7.8kHz时相位精度不好，可能保不住D=0.003的精度指标。当然，以实测为准。
16、电感测量准确吗？
L、C、R测量，基本上是等精度的，都可以达到0.3%的指标。
大部分坛友手上没有标准电感器，所以此项工作不好验证。可以使用空心线圈与商品精密电桥进行对比测试，但有一些技巧。电感器的接线端子要固定好，不可使用软线。空心线圈周围不能有铁质材料，也不能有磁铁等东西，以免影响电感量。
17、电阻测试中，有时测量误差不连续，如测量2.000k电阻，得到2.000读数，一字不差，而测量5.000k电阻，却相差了8字，正常吗？
  是正常的，因为，两次测量中，程序自动判断量程，使用了不同的增益档位。
18、二线法测量1000uF电容，7.8kHz频率下，容量变大，这正常的吗？
  这是正常的。这是因为表笔串联电感及电容器内部的导体串联电感的影响变大，使得电容的视阻抗变小，表现出的电容量就变大了。
  四线法或短路清零法可以消除表笔电感的影响，但无法消除电容器内部导体电感的影响。
表笔并联电容，约每10cm有0.5至1pF，长度按单支笔计算
表笔串联电感，约每10cm有0.1uH，长度按回路线长计算，与线径、导线回路形状有一定关系
表笔电阻，约15至150毫欧，与线径、线长度紧密关联。
二线法的残余阻抗是比较大的，比如表笔电感0.2uH，那么7.8kHz时电抗是10mR。今测470uF电容，它的电抗将是-50mR左右。受表笔电感的影响，实测到的串联电抗将是10mR - 50mR = -40mR，也就是说，电抗测值将变小20%左右，所得容量会增加20%，因此，用二线法在7.8kHz测电解电容，容量会变大很多，甚至变大几倍或干脆变为电感。引脚细的电容，电容内部的导线电感更大，更容易变成电感，而不是电容。如果改用1kHz测量，那么该电容电抗约为400mR，表笔电抗约为1.2mR，显然，表笔电抗可以忽略。所以测电解，要使用100Hz、1kHz测容量，测电解ESR一般使用7.8kHz
19、电解电容的ESR测量应使用哪个频率
  三个频率下都可以测量。使用7.8kHz频率测出的ESR，更能反应电容器的质量。
20、测量结果为3xxx至9xxx读数时，末字常有跳动，特别是9xxx时，末字跳得更多，正常吗？
  对于本表来说，这是正常的，末字的小量跳动，不影响精度。本表AD过采样噪声、DDS、相位发生器等全部集成在一个芯片，所以噪声大一些，但对精度影响不大。
  主量程内，读数为1xxx至3xxx，通常末字跳一字（高阻与低阻测量除外）。
21、用电阻与CBB/630V电容串联，测试相位精度，可以吗？
  可以的，但意义不大。因为，直接用CBB/630V电容验证相位，如果LCR表准了（显示为999），那么串联电阻测量，在误差许可范围内一定会得到预期值的。
  因此，只要电阻测量“阻值准”，电容测量“相位准”，那么这个LCR表就准了。前提是晶振频率要准确。
22、相位校准后，测量Q>1000的电容，得不到999要怎么办？
  如果测得损耗电阻是负数，而且显示的Q值是600左右，说明相位误差大了一些，建议适当微调R1X——R4X，通常微调1至2字即可，不可微调过多。
  如果损耗电阻是正数，而且显示的Q值是600左右，其实相位误差很小了，不用调整了。
23、用两个电容串、并联验证精度，可以吗？
  使用此法，要使用CBB或涤容等电容。涤纶电容还要求在同频率下测试。
  如，测得两个电容是C1与C2，那么并联后，测值应为C1+C2，串联后是C1*C2 / (C1+2)，以此验证。
24、两个相同的高Q电容（Q>1000），并联或串联后Q值是多少。
  还是Q>1000
25、Q与D值的计算公式
  一个电抗元件，可以等效为两个串联集中参数X与R，写作Z = R + j X
  Q = | X / R |，习惯上只取正，所以取绝对值。
  D = | R / X |，习惯上只取正，所以取绝对值。
  一个电抗元件，也可以等效为两个并联集中参数X2与R2，写作1 / Z = 1 / R2 + j / X2
  Q = | R2 / X2 |，习惯上只取正，所以取绝对值。
  D = | X2 / R2 |，习惯上只取正，所以取绝对值。
  D与Q是互为倒数的。
25、什么是“串联法”与“并联法”
  一个电抗元件，可以等效为两个串联集中参数X与R，写作Z = R + j X
  取倒数后，就转为并联参数，即1 / Z = 1 / (R+jX) = (R-jX) / (R^2+X^2) = R / (R^2+X^2) – jX / (R^2+X^2)
  相当于并联电抗为X2 = (R^2+X^2) / X，并联电阻为R2 = (R^2+X^2) / R
  串联法与并联法，所得电抗不同，但得到的Q值是相同的。
  X2与R2还可以写为：
X2 = (R^2+X^2) / X = X [ (R/X)^2 + 1 ] = X ( D^2 + 1 )
R2 = (R^2+X^2) / R = R [ (X/R)^2 + 1 ] = X ( Q^2 + 1 )
26、涤纶电容的Q值大约是多少？
  容量小的，7.8kHz频率下，Q一般大于100，1kHz频率下，Q大于200也是正常的。
  容量大的，如1uF或2uF，Q值通常会小一点。
27、CBB/ 630V电容电容的Q值大约是多少？
  一般大于1000，我手上的CBB/630V 0.1uF、0.33uF、0.47uF电容，Q值大于1500
   0.47uF的，随频率升高，Q值下降，1kHz下Q>2500，7.8kHzQ>1300，这是因为，容量大的，引线及内部金属的串联电阻不可忽略，所以Q值随频率升高而下降。
   0.1uF的，在10kHz以下频率，Q值为常数。这时，损耗主要是介质损耗为主，金属串联损耗可以忽略，所以Q值保持不变。
28、高阻电阻测量使用串联法还是并联法
  建议使用并联法。LCD1602上的显示的标识符是“Zp”
29、低阻测量应使用串联法还是并联法
  须使用串联法。LCD1602上的显示的标识符是“Zs”
30、蜂鸣器太响怎么办？
  蜂鸣器响起时，比较大声，如果觉得不适，可以拆除或在发声孔贴上粘纸。
  每次按下按键，蜂鸣器电流会影响测量，所以要等蜂鸣停响几秒钟后测值才能稳定下来。
31、TL082的输出幅度要求及幅度调整
   正常情况下，100Hz输出峰值200mV，1kHz输出峰值180mV，7.8kHz输出峰值190mV
   采用电路图中的参数，100Hz与1kHz的输出幅度会自动达到上述值。7.8kHz档由于滤波电容误差，输出幅度可能会有一些误差。如果7.8kHz时幅度误差过大，调整C24电容的容量即可。
   幅度超过上述值10%，LCR不一定能够正常工作，偏小10%则没有问题。
32、为什么未进行零点校正LCR无法正常工作，测值严重异常。
  AD没有负值测量能力，而且存在零点门槛电压。为此OP07输出后加了直流偏置，以便准确测量鉴相器的输出。在直流偏置做用下，鉴相器输出为0时AD读数是75左右。检相器输出负电压时，AD读数则小于75，但AD永远不会读出负数结果。对于负电压，要再加上180度移相的方波进行鉴相，以便得到正电压输出，否则AD无法正确工作。由于AD得不到负数结果，所以程序无法判断是否要180度翻转。
  当我们进行了零点校准后，鉴相器输出负电压时，AD输出结果也会是负数，只是最负只到-75而已，但这已足够用来做相位判断了。
33、如何选择LCR表的电容
毫伏表信号通路中滤波相关的C5——C10、C25、C26，应采用容量不随信号电压变化的电容。涤纶、CBB电容即可。
C1——C4，应使用低漏电的电容，耐压大于63V。涤纶、CBB电容均可。
DDS滤波器电容应使用温漂小一点的电容，如涤纶电容。若采用独石电容，温漂可能会大一些，能否使用未测试。
C11——C13、C15——C17、C27，可使用独石电容，建议使用涤纶或CBB电容。
34、整机功耗是多少
  正5V耗电50—60mA，与LCD1602背光灯电流大小有关。负5V耗电小于50mA，继电器未动作时，小于20mA
35、如何选用变压器
  使用9V带抽头变压器。变压器空载电压比标称电压高1至2V。如9V变压器的空载电压可能是11V，如果变压器功率大，整流输出电压将偏大，7805会发热。因此，变压器功率大时建议使用8V变压器即可。当市电源电压是220V时，7805前端电压为9至10V比较合适，超过11就不大好。
  如果买不到带抽头的变压器，也可以使用无抽头的变压器。一端接在地线，另一端接在余下两端子中的任意一个即可。这种方法，整流电路变为半波整流，输出纹波变大，有必要用示波器看一下7805前端的最低电压，不得低于9V（220V）。
36、LCD1602与主板连接使用几条线
  电源线2条，1脚接地，2脚接电源+5V
  数据线4条，11、12、13、14脚
  控制线3条，第5脚是R/W控制线，因程序没有进行写数据操作，该脚可以直接在LCD1602的PCB板上接地，所以控制线实际只需接2条。
  所以，最少需要8条连接线。
37、串联模式下复阻抗的绝对误差是多少
  Z = R+jX，误差a = ( |R| + |X| ) / 300
  R的真值是：R-a < R+a，R按正值算
  X的真值是：X-a < X+a，X按正值算
  如，测得电容的阻抗是 ( 0.22 - j20 )欧，那么a=(0.22+20)/300=0.07欧，电阻R与电抗X误差均为0.07欧
  如，电阻与一个电容串联后，测得的电抗是 ( 15 - j20 )欧，那么a = (15+20) / 300 = 0.12欧，电阻部分R与电抗部分X误差均为0.12欧
  以上算法对串联模式有效。
38、为什么频率不是整数？
  1、DDS的钟频只有62.5kHz，造成输出频率分辨力不足。
  2、为了减小相位噪声，取钟频1/8，频率是7.8125kHz
39、为什么短路或开路后视值是乱跳的？
短路时，测得的值是表笔的短路残余阻抗。由于表笔的残余阻抗小，当量程选择不正确时，表笔残余值可能小于LCR的最小分辨力（即下限超量程），此时视值是乱跳的。
开路时，测得的是开路残余阻抗。开路阻抗很大，当量程选择不正确时，残余值可能大于LCR最大分辨力（即上限超量程），此时视值也是乱跳的。
20R、1k、10k、100k档，阻抗下限分别是1毫欧，50毫欧、500毫欧、70k欧左右显示溢出，上限与表笔有关，但各档最大不会超过500k、20M、200M、1G欧，7.8kHz小于100M欧
40、LCD1602的背光电流多少比较合适?
  电流大，屏的亮度高，有些刺眼。有的LCD背光LED本身亮度低，所需电流也就大一些。通常10mA足够，背光源LED限流电阻取100至200欧即可。
41、R4b与G2b参数有何作用？
  是用于调整100k档和9倍增益档的7.8kHz下的精度。只是一个微调参数，一般要求10以内，不要超过10字，以免影响了整体精度。
42、本表可以用作电容器在线检查工具吗？
  可以，但不适合。因为前端保护电路不够严格，如果被测电容带电，可能伤了仪表。
43、夹具的选择与制作
  以下两种方示均可
  用Q9插座，使用四线法，带屏蔽开尔文夹具
  用香蕉插座，引线采用0.75平方，线长用10cm（不含夹具），夹子采用小铁夹。引线如果选用50cm，是比较长的，不能用于校准，也不宜用于高阻测定。也就是说，最好备有长、短两套线夹。
44、如何快速检验LCR的准确性?
  不同频率分别做以下测试
  1)、20档测定20R、25R、100R电阻是否准确
  2)、1k档测定200R、500R、1k、3k、5k、10k、20k电阻是否准确
  3)、10k档测定5k、10k、20k、50k、100k电阻是否准确
  4)、100k档测定90k、100k、150k、200k电阻是否准确（最好用并联法测量）
  相位验证
  1)、取0.33uF和0.47uF CBB/630V电容，20R/7.8kHz档，测得Q>500，最好测到999
  2)、取0.1uF和0.05uF和0.022uF CBB/630V电容，1k/7.8k档，测得Q>500，最好测到999
  3)、取1n和3.3n 高Q电容，10k/7.8kHz档，测得Q>500，最好测到999
  4)、取220pF NPO，100k/7.8kHz档，测得Q>500，最好测到999
  5)、以上电容在1kHz，并选择最佳量程，也应测到500以上，选100Hz应得到300以上(该频率下本表相位误差大)
  低阻验证
  1)、将表笔短路，保持表笔状态不变，三个频率下测得的表笔电阻应相同，相差小于2mR，并且1kHz档显示的表笔电感与7.8kHz显示相差小于0.2uH
  2)、四线法，用2.5平方铜线短路，电抗与电阻都应小于2mR
  高阻验证
  1)、取1M、2M、4M等电阻测试，用并联法（即Zp状态而不是Zs），1M以下误差应小于1.5%
2)、7.8kHz测4M时误差达到3%也是正常的
45、如何给DIY的表确定标称误差
  在2欧至200k欧范围内，用电阻高密度测试，测量时，采用最佳量程。如果误差小于0.2%，则那么可以标称为0.3%，如果误差小于0.3%，则应标称为0.5%
  电抗X的精度与电阻测量是等精度的。
电感与电容的精度则与“集中参数测定”模型的精度有关，也就是说元件是理想模型，就得到高精度。理想LC按以下换算：
  电感与电抗X换算关系：L = X/(2*PI*f)
  电容与电抗X换算关系：C = 1/(2*PI*f*X)

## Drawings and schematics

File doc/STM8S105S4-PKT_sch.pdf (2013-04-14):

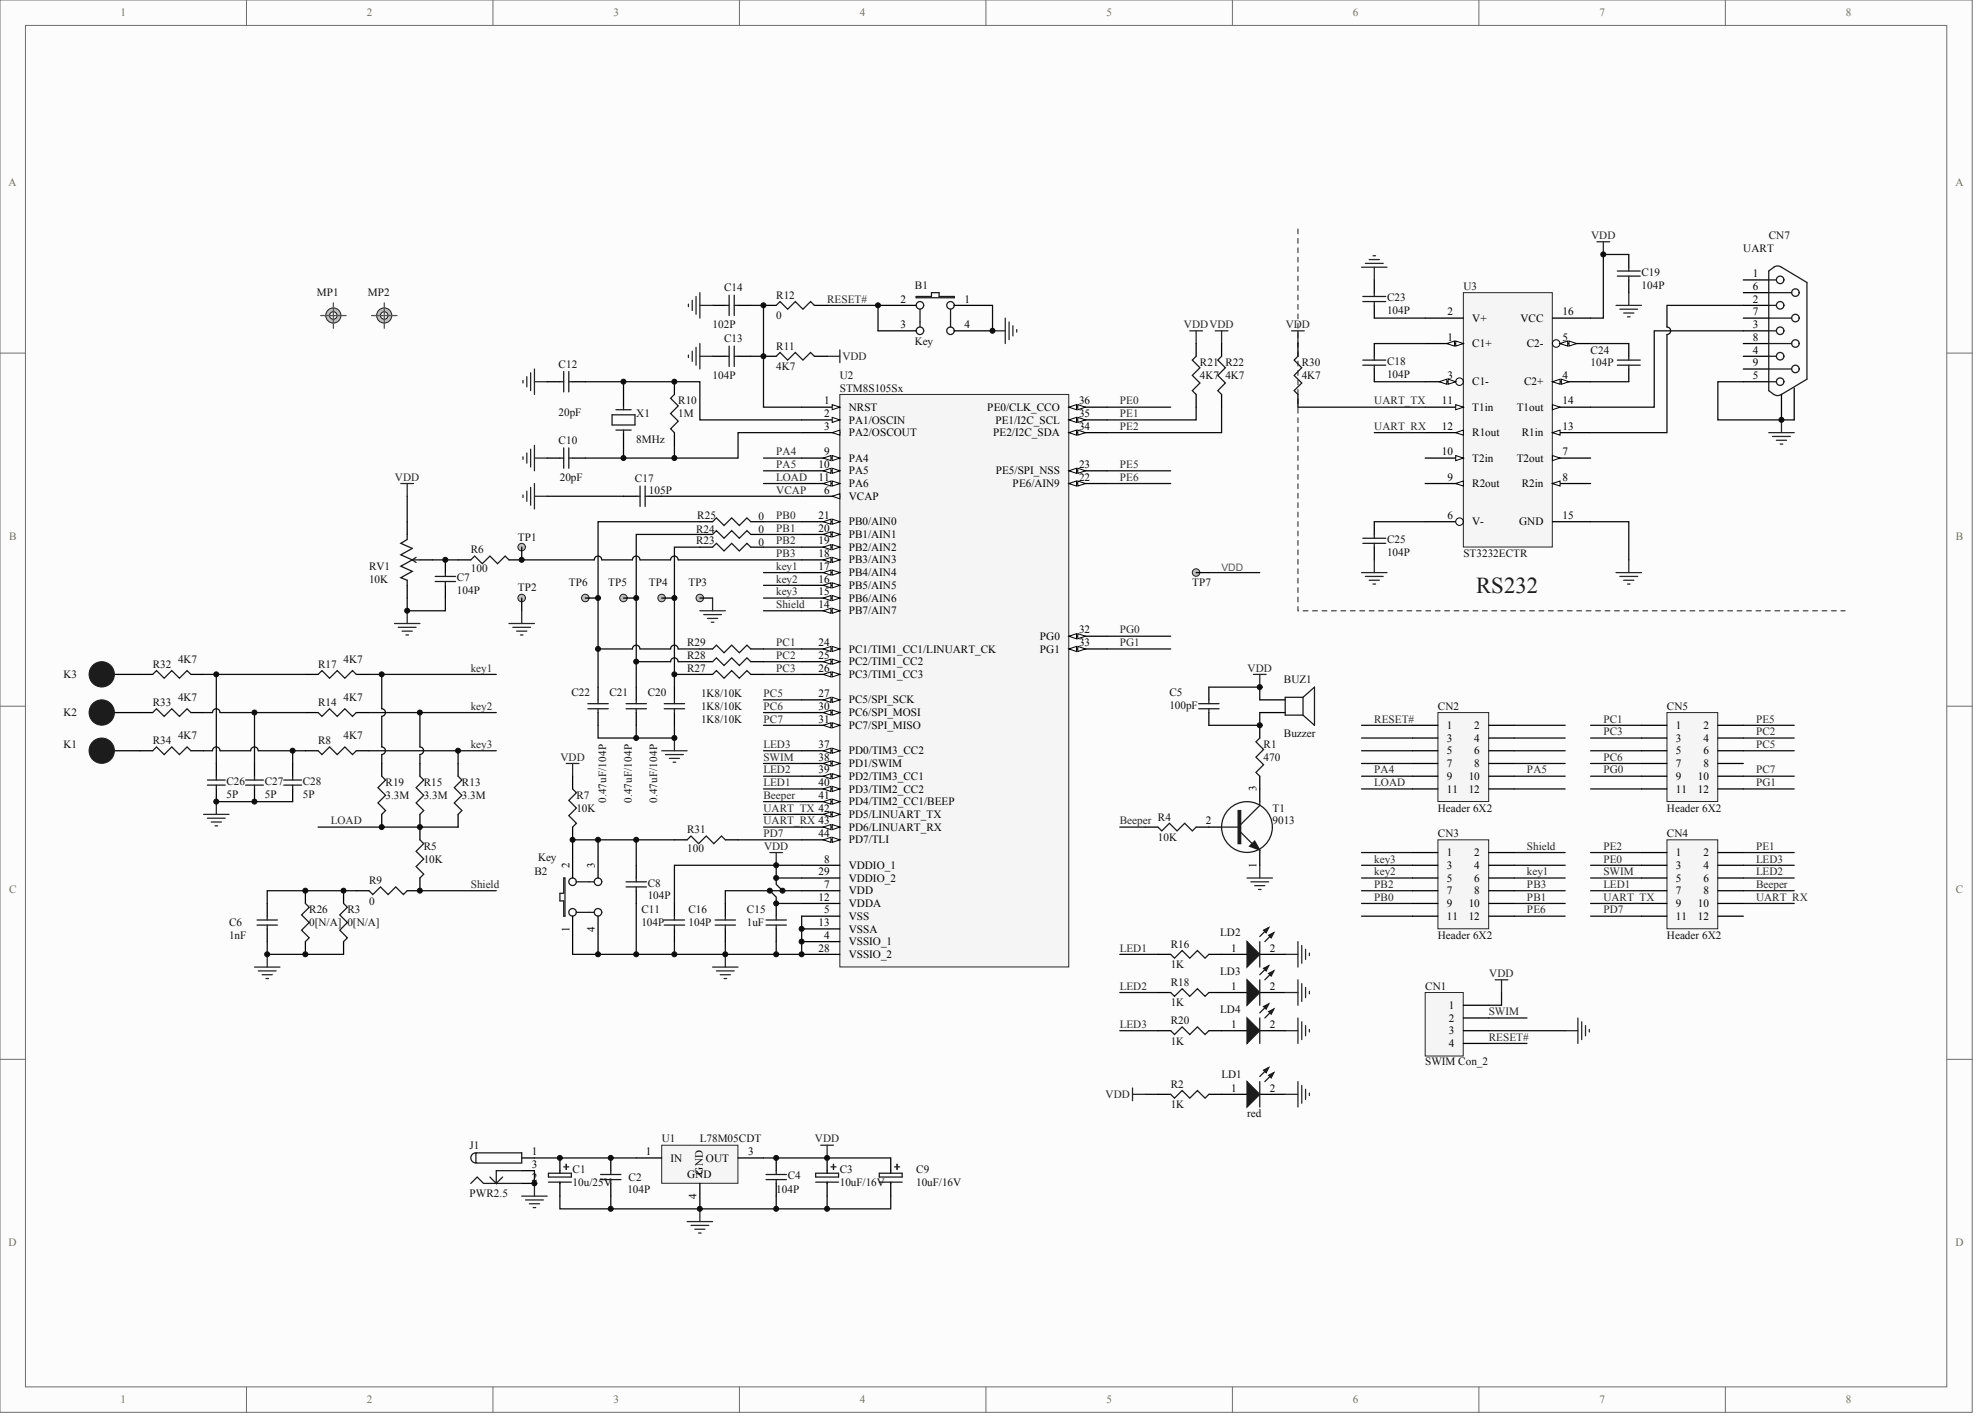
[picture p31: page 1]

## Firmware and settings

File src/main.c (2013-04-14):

/**
  **********************************************************
  * @file    Project/main.c
  * @author  Holts
  * @version V1.0.0
  * @date    2012-12-9
  * @brief   Main program body
  **********************************************************
	*/
/* Includes ----------------------------------------------*/
#include "stm8s.h"              
#include "parameter.h"
#include "ptask.h"
#include "main.h"
#include "HD44780.h"
#include "delay.h"


/* Private typedef ---------------------------------------*/

/* Private macro -----------------------------------------*/

/* Private variables -------------------------------------*/
u8  temp_AD_H;					   // temporary registers for reading ADC result
u8  temp_AD_L;             // temporary registers for reading ADC result
u8	ADInit;						     // flag for ADC initialized
u8	ADSampRdy;				     // flag for filed of samples ready
u8  AD_samp;						   // counter of stored samples
u16 AD_sample[NUMB_SAMP];	 // store samples field 
u16 AD_avg_value;				   // average of ADC result
	
volatile unsigned char timers[MAXTASKS];
 
u8  Trg;
u8  Cont;

bool Auto = FALSE;
u8  Mode = MODE_R;
u8  Frq = SEL_1K;
short int  Range = RNG_40;
u8  Gain;

volatile bool event = TRUE;
volatile u16 ten_ms = 0;
volatile u16 sec = 0;
volatile u16 min = 0;

/* Define 6 custom characters to display bar graph*/
char STCustom[48] =
  {
    0x00, 0x00, 0x00, 0x00, 0x00, 0x00, 0x00, 0x00, // Blank
    0x10, 0x10, 0x10, 0x10, 0x10, 0x10, 0x10, 0x10, // 1column  |
    0x18, 0x18, 0x18, 0x18, 0x18, 0x18, 0x18, 0x18, // 2columns ||
    0x1c, 0x1c, 0x1c, 0x1c, 0x1c, 0x1c, 0x1c, 0x1c, // 3columns |||
    0x1e, 0x1e, 0x1e, 0x1e, 0x1e, 0x1e, 0x1e, 0x1e, // 4columns ||||
    0x1f, 0x1f, 0x1f, 0x1f, 0x1f, 0x1f, 0x1f, 0x1f, // 5columns |||||
  };

/* Stores the sin structure in ram */
Sin_Typedef sin;
/* The counter variable for counting the Update cycles in TIM1 */
u8 counter = 0;   
/* This shows the value of the samples for the different no of samples in half
sine wave. The last value corresponds to the amplitude of the sine wave.*/
CONST u8 sample[16]={0,10,21,31,41,50,59,67,74,81,87,91,95,98,99,100};



 

  u16 i, count;
  u8 char_pos, roll;
  /* Custom characters can be 8 max. user defined characters from 0 to 7*/
  /* disp[] string is here to generate the display of custom characters on LCD*/
  /* of the bar graph using 8 characters pattern*/
  /* Example: printing "\0\0\0\0\0\0\0\0\n" will display 8 times character 0*/
  /* which is the blank character*/
  /* Example: printing "\5\5\5\5\5\5\5\5\n" will display 8 times character 5*/
  /* which is the 5 columns character*/
  char disp[] = "\0\0\0\0\0\0\0\0\n";
  char message[5][7] = {"STM8S", "Value", "Line", "8-Bit", "Micro"};



/* Private function prototypes ---------------------------*/
/**
  * @brief Count average of samples stored in the u16 field
  * @par Parameters:
  *  *p: pointer to the begin of the field
  * smp: number of samples in the field
  * @retval Average u16 value
  */
u16 u16_average(u16 *p, u8 smp) 
{ 
	u8 i;
	u16 sum;
	
	for(i=0, sum= 0; i < smp; ++i)
		sum+= *p++;		
	return sum / smp;
}

/**
  **********************************************************
  * @brief Configures clocks
  * @par Parameters: None
  * @retval void None
  * @par Required preconditions: None
  **********************************************************
  */
void CLK_Configuration(void)
{ /* Fmaster = 8MHz */
  CLK_HSIPrescalerConfig(CLK_PRESCALER_HSIDIV2);
}

/***********************************************************
  * @brief Configures GPIOs
  * @par Parameters: None
  * @retval void None
  * @par Required preconditions: None
  **********************************************************
  */
void GPIO_Configuration(void)
{
  /* GPIO reset */
  GPIO_DeInit(LCDPort);
  /* Configure LCDPort D0 output push-pull low LCD Bus*/
  GPIO_Init(LCDPort, GPIO_PIN_0, GPIO_MODE_OUT_PP_LOW_FAST);
  /* Configure LCDPort D1  output push-pull low LCD Bus*/
  GPIO_Init(LCDPort, GPIO_PIN_1, GPIO_MODE_OUT_PP_LOW_FAST);
  /* Configure LCDPort D2  output push-pull low LCD Bus*/
  GPIO_Init(LCDPort, GPIO_PIN_2, GPIO_MODE_OUT_PP_LOW_FAST);
  /* Configure LCDPort D3  output push-pull low LCD Bus*/
  GPIO_Init(LCDPort, GPIO_PIN_3, GPIO_MODE_OUT_PP_LOW_FAST);
	
  /* GPIO reset */
  GPIO_DeInit(LCDControlPort);
  /* Configure LCDPort E output push-pull low LCD Enable Pin*/
  GPIO_Init(LCDControlPort, LCD_Enable, GPIO_MODE_OUT_PP_LOW_FAST);
  /* Configure LCDPort RS output push-pull low LCD RS Pin*/
  GPIO_Init(LCDControlPort, LCD_RS, GPIO_MODE_OUT_PP_LOW_FAST);
	
	/* GPIO reset */
  GPIO_DeInit(LCDPwrPort);
  /* Configure LCDPwrOnPort VDD output push-pull low LCD Power Supply*/
  GPIO_Init(LCDPwrPort, LCDPwrPin, GPIO_MODE_OUT_PP_LOW_FAST);

	/* GPIOD reset */
  //GPIO_DeInit(BUTTON_PORT);
	/* Configure PC4 (push button) as input floating */
  GPIO_Init(BUTTON_PORT, BUTTON_PIN, GPIO_MODE_IN_PU_NO_IT);
	/* Configure PD0 (LED1) as output push-pull low (led switched on) */
  //GPIO_Init(GPIOD, GPIO_PIN_0, GPIO_MODE_OUT_PP_LOW_FAST);
	
	/* ADC reset */
	GPIO_DeInit(ADC_GPIO_PORT);
	GPIO_Init(ADC_GPIO_PORT, ADC_INPUT, GPIO_MODE_IN_FL_NO_IT);
	
	/* FRQ reset */
	GPIO_DeInit(FRQ_GPIO_PORT);
	GPIO_Init(FRQ_GPIO_PORT, FRQ_GPIO_PINS, GPIO_MODE_OUT_PP_LOW_FAST);
	
	/* RANGE reset */
  GPIO_DeInit(RANGE_GPIO_PORT);   
  GPIO_Init(RANGE_GPIO_PORT, RANGE_GPIO_PINS, GPIO_MODE_OUT_PP_LOW_FAST);
}

/***********************************************************
  * @brief TIM1 init
  * @par Parameters: None
  * @retval void None
  * @par Required preconditions: None
  **********************************************************
  */
void TIM1_Config(void)
{
	TIM1_DeInit();
		
	/* Time Base configuration */
  /*
		   TIM1_Prescaler = 4   分频 8 / 4 = 2MHz
       TIM1_Period = 1999   频率 2000K /(1999 +1) = 1KHz
       TIM1_CounterMode = TIM1_COUNTERMODE_UP
			 TIM1_RepetitionCounter = 0
    */
	TIM1_TimeBaseInit(4, TIM1_COUNTERMODE_UP, AUTORELOAD, 0);
	
  // set autoreload register for trigger period
	//TIM1->ARRH= (u8)(AUTORELOAD >> 8);	 
	//TIM1->ARRL= (u8)(AUTORELOAD);			   
	//TIM1_SetAutoreload(AUTORELOAD);
	
	// set compare register for trigger period
	//TIM1->CCR1H= (u8)((AUTORELOAD-AD_STAB) >> 8);   
	//TIM1->CCR1L= (u8)(AUTORELOAD-AD_STAB);
	TIM1_SetCompare1(AUTORELOAD-AD_STAB);
	
	// auto reload register is buferred
	//TIM1->CR1|= TIM1_CR1_ARPE;	  
	TIM1_ARRPreloadConfig(ENABLE);
	
	// CC1REF is used as TRGO
	//TIM1->CR2= (4<<4) & TIM1_CR2_MMS;		            
	TIM1_SelectOutputTrigger(TIM1_TRGOSOURCE_OC1REF);
	
	// CC1REF in PWM 1 mode
	//TIM1->CCMR1= (6<<4) & TIM1_CCMR_OCM;	          
	TIM1_SelectOCxM(TIM1_CHANNEL_1, TIM1_OCMODE_PWM1);
	
	// CC1 interrupt enable
	//TIM1->IER|= TIM1_IER_CC1IE;		     
	TIM1_ITConfig(TIM1_IT_CC1, ENABLE);
	
  // CC1 negative polarity
	//TIM1->CCER1|= TIM1_CCER1_CC1P;	  
	TIM1_OC1PolarityConfig(TIM1_OCPOLARITY_LOW);
	// CC1 output enable
	//TIM1->CCER1|= TIM1_CCER1_CC1E;	  
  TIM1_CCxCmd(TIM1_CHANNEL_1, ENABLE);
		
	// synchronization of TRGO with ADC
	//TIM2->SMCR|=  TIM2_SMCR_MSM;	   
	TIM1_SelectMasterSlaveMode(ENABLE);
	
	
  /* PWM configuration */
  /*
       TIM1_OCMode = TIM1_OCMODE_PWM1
       TIM1_OutputState = TIM1_OUTPUTSTATE_ENABLE
       TIM1_Pulse = INIT_TIM1_CCR1
       TIM1_OCPolarity = TIM1_OCPOLARITY_LOW
  */
  TIM1_OC2Init(TIM1_OCMODE_PWM1, TIM1_OUTPUTSTATE_ENABLE, TIM1_OUTPUTNSTATE_DISABLE,
               INIT_TIM1_CCR1, TIM1_OCPOLARITY_LOW, TIM1_OCNPOLARITY_LOW, 
               TIM1_OCIDLESTATE_RESET, TIM1_OCNIDLESTATE_RESET);
		
	/* Update Interrupt Enable */
  TIM1_ITConfig(TIM1_IT_UPDATE, ENABLE);
	
	  
  /* Enable TIM1 */
  TIM1_Cmd(ENABLE);
  
  /* Enable CC1 output*/
  TIM1_CtrlPWMOutputs(ENABLE);
	
}

/***********************************************************
  * @brief  Configure TIM4 to generate an update interrupt each 1ms 
  * @param  None
  * @retval None
	**********************************************************
  */
void TIM4_Config(void)
{
  /* TIM4 configuration:
   - TIM4CLK is set to 16 MHz, the TIM4 Prescaler is equal to 128 so the TIM1 counter
   clock used is 16 MHz / 128 = 125 000 Hz
  - With 125 000 Hz we can generate time base:
      max time base is 2.048 ms if TIM4_PERIOD = 255 --> (255 + 1) / 125000 = 2.048 ms
      min time base is 0.016 ms if TIM4_PERIOD = 1   --> (  1 + 1) / 125000 = 0.016 ms
  - In this example we need to generate a time base equal to 1 ms
   so TIM4_PERIOD = (0.001 * 125000 - 1) = 124 */

  /* Time base configuration */
  TIM4_TimeBaseInit(TIM4_PRESCALER_128, TIM4_PERIOD_MS);
  /* Clear TIM4 update flag */
  TIM4_ClearFlag(TIM4_FLAG_UPDATE);
  /* Enable update interrupt */
  TIM4_ITConfig(TIM4_IT_UPDATE, ENABLE);
  
  /* Enable TIM4 */
  TIM4_Cmd(ENABLE);
}


/***********************************************************
  * @brief ADC Init
  * @par Parameters: None
  * @retval void None
  * @par Required preconditions: None
  **********************************************************
  */
void ADC_Config( void )
{
 	//ADC1->CSR= ADC1_CSR_EOCIE | (3 & ADC1_CSR_CH);  
	// ADC EOC interrupt enable, channel 3
	ADC1_ITConfig(ADC1_IT_EOCIE, ENABLE);
	ADC1_ConversionConfig(ADC1_CONVERSIONMODE_SINGLE, ADC1_CHANNEL_3, ADC1_ALIGN_LEFT);
	
	//ADC1->CR1= 4<<4 & ADC1_CR1_SPSEL;			          
	// master clock/8, single conversion
	ADC1_PrescalerConfig(ADC1_PRESSEL_FCPU_D8);
	
	//ADC1->CR2= ADC1_CR2_EXTTRIG;					          
	// external trigger on timer 1 TRGO, left alignment
	ADC1_ExternalTriggerConfig(ADC1_EXTTRIG_TIM, ENABLE);
	
	//ADC1->TDRH= 2;									                
	// disable Schmitt trigger on AD input 9
	//ADC1->TDRL= 0;                                  
	ADC1_SchmittTriggerConfig(ADC1_SCHMITTTRIG_CHANNEL3, DISABLE);
	
}

/***********************************************************
  * @brief Key Read
  * @par Parameters: None
  * @retval void None
  * @par Required preconditions: None
  **********************************************************
  */
void KeyRead( void )
{
    //unsigned char ReadData =  GPIO_ReadInputData(KEY_GPIO_PORT)^0xFF;   
		//ReadData = ReadData & 0x0E;
		u8 ReadData  = (GPIO_ReadInputData(BUTTON_PORT)^0x80) & 0x80;
    Trg = ReadData & (ReadData ^ Cont);       
    Cont = ReadData;                 
}

/***********************************************************
  * @brief Delay before completing the action
  * @param[in] function action() to be performed once the delay past
  * @param[in] None
  * @retval void None
  * @par Required preconditions: None
  **********************************************************
  */
u8 Key_thread()
{
  PTH_BEGIN
	  while (1)
		{
		  WaitX(20);
		  if(Trg)  
			{  
				 if (Trg & BUTTON_PIN)   
				 {  
					   Range =  (Range - 1) % 4; 
						 if (Range < 0) Range = RNG_100K;
						 LCD_LOCATE(1, 10);
         		 if (Range == RNG_40) {RANGE_40;LCD_printf("%s", "40  ");}
						 if (Range == RNG_1K) {RANGE_1K;LCD_printf("%s", "1K  ");}
						 if (Range == RNG_10K) {RANGE_10K;LCD_printf("%s", "10K ");}
						 if (Range == RNG_100K) {RANGE_100K;LCD_printf("%s", "100K");}
				 }
				 if (Trg & KEY_MENU)
				 { 
				   Mode = (Mode + 1) % 3; 
					 LCD_LOCATE(1, 8);
					 if (Mode == MODE_R)  LCD_printf("%s", "R"); 
					 if (Mode == MODE_C)  LCD_printf("%s", "C"); 
					 if (Mode == MODE_L) 	LCD_printf("%s", "L"); 
		     }
				 if (Trg & KEY_FRQ)
				 { 
				   Frq = (Frq + 1) % 3; 
					 LCD_LOCATE(1, 1);
				   if (Frq == SEL_100) {FRQ_100;LCD_printf("%s", "F 100");}
					 if (Frq == SEL_1K) {FRQ_1K;LCD_printf("%s", "F 1K ");}
					 if (Frq == SEL_7K8) {FRQ_7K8;LCD_printf("%s", "F 7K8");}
				 }
         if (Trg & KEY_REDUCE) 
				 {
						 Range =  (Range - 1) % 4; 
						 if (Range < 0) Range = RNG_100K;
						 LCD_LOCATE(1, 10);
					   if (Range == RNG_40) {RANGE_40;LCD_printf("%s", "40  ");}
						 if (Range == RNG_1K) {RANGE_1K;LCD_printf("%s", "1K  ");}
						 if (Range == RNG_10K) {RANGE_10K;LCD_printf("%s", "10K ");}
						 if (Range == RNG_100K) {RANGE_100K;LCD_printf("%s", "100K");}
					}
		     if (Trg & KEY_PLUS) 
				 { 
						 Range = (Range + 1) % 4; 
						 LCD_LOCATE(1, 10);
					   if (Range == RNG_40) {RANGE_40;LCD_printf("%s", "40  ");}
						 if (Range == RNG_1K) {RANGE_1K;LCD_printf("%s", "1K  ");}
						 if (Range == RNG_10K) {RANGE_10K;LCD_printf("%s", "10K ");}
						 if (Range == RNG_100K) {RANGE_100K;LCD_printf("%s", "100K");}
					}
		  }
	  }
  PTH_END
}	

/**
  * @brief  Init Sin Struct
  * @param  None
  * @retval None
  */
static void LoadValueIntoSinStruct(void)
{
  uint8_t  offset=0,diff=0;
  
  while(offset <= (nbr_of_samples_half/2))
  {
    /*First half of upper half samples of sine wave is loaded into "value" of sin structure.*/
     sin.Value[offset] = sample[offset]; 
     offset++;                      
  }
  diff = (uint8_t)(offset - 1);
  while(offset < nbr_of_samples_half)
  {                                    
      diff--;  
      /* Second half of upper half samples of sine wave is loaded into "value" of sin structure.*/
      sin.Value[offset] = sample[diff];    
      offset++;                         
  }  
  /*Index is initialized to 0.Sin wave upper half is generated at start*/
  sin.Index = 0;                      
  sin.Up = TRUE;                      
}
 
 
/* Public functions --------------------------------------*/
/**
  * @brief Validation firmware main entry point.
  * @par Parameters: None
  * @retval void None
  */  
void main(void)
{
	/* The counter value is initialized to 0.*/
  counter = 0;
  LoadValueIntoSinStruct();           
	
	/* Init CLK */
	CLK_Configuration();
 
  /* Init GPIOs*/
  /* This function sets GPIOs pins according to LCD pins assignment in main.h*/
  GPIO_Configuration();
	
	/* BEEP calibration */
  //BEEP_LSICalibrationConfig(9000);
 
  /* TIM1 configuration */
  TIM1_Config();
  
	/* TIM4 configuration */
  TIM4_Config();
	
	/*  ADC INITIALIZATION  */
	ADC_Config();

	//GPIOC->DDR|= 0x02;						// PC.1 as push-pull outputs
	//GPIOC->CR1|= 0x02;
		
	//GPIOE->CR1&=~0x40;					  // PE.6 as a floating input
	//GPIOE->DDR&=~0x40;
	
  // init ADC variables
	AD_samp= 0;						    // number of stored samples 0
	ADInit= TRUE;             // ADC initialized 
	ADSampRdy= FALSE;         // No sample 
	
	// ADC on
	ADC1_Cmd(ENABLE);
  
	// enable all interrupts 
	enableInterrupts();				   
	
	/* Set power supply on LCD via LCD Power Pin */
  //LCD_PWRON();
  /* Min. delay to wait before initialization after LCD power ON */
  /* Value is ms units*/
  Delay(100);
  /* Initialization of LCD */
  LCD_INIT();
  /* LCD Clear Display */
  LCD_CLEAR_DISPLAY();
  /* Set @CGRAM address start */
  LCD_CMD(CGRAM_address_start);
  /* Loading 6 characters @CGRAM address from STCustom tab */
  LCD_LOAD_CGRAM(STCustom, 6);

	/* Welcome application message while delay 3000ms */
  /* Set cursor to the chosen position*/
  LCD_LOCATE(1, 1);
  /* Print string on LCD (must be ended with \n)*/
  LCD_printstring(" LCR 2.0 \n");
	LCD_LOCATE(2, 2);
  LCD_printstring("XJW Putian,2011\n");
	Delay(3000);
	LCD_CLEAR_DISPLAY();

  /* Init local variables*/
  roll = 0;
  count = 0;
	
  /* Init global variables*/
  ten_ms = 0;
  sec = 0;
  min = 0;
	
	FRQ_1K
	LCD_LOCATE(1, 1);
	LCD_printf("%s", "F 1K ");
	
	LCD_LOCATE(1, 8);
	LCD_printf("%s", "R");
	
	RANGE_40
	LCD_LOCATE(1, 10);
	LCD_printf("%s", "40  ");
	
  //*** MAIN LOOP ***	
	while (1) 
	{
		/* 读键值 */
		KeyRead();
		
		/* 键盘处理 */
		RunTask(Key_thread,1); 
				
		/* 声音处理 */
		//Beep_thread(&pt2);
 		 
		/* ADC取样　*/
		if (ADSampRdy == TRUE)  // field of ADC samples is ready?
		{	 // average of samples
			AD_avg_value= u16_average(&AD_sample[0], AD_samp); 
			
			AD_samp= 0;				        // reinitalize ADC variables
			ADSampRdy= FALSE;
					
      /* Display ADC value at the top right*/
			LCD_LOCATE(1, 13);
      /* Uses special mask*/
      LCD_printf("%4d", AD_avg_value);
		}

    /* If event true (1 sec elapsed) then display rolling messages*/
    if (event == TRUE)
      {
        event = FALSE;
        LCD_LOCATE(2, 11);
        /* Message is displayed at the bottom right*/
        /* Uses special mask*/
        LCD_printf("%5s", message[roll]);
        /* Message changes every time (5 times) then return to first word*/
        /* Table index "roll" is set accordingly*/
        roll = (roll + 1) % 5;
      }
		
		/* Display time counter Min:Sec:Ten ms at the bottom left*/
    LCD_LOCATE(2, 1);
    /* Uses special mask*/
    LCD_printf("%02d:%02d:%02d", min, sec, ten_ms);

    /* Display each 6 (0 to 5) custom characters at same LCD position*/
		//char_pos = 0;
		//while (char_pos < 8)
		//{
      //for (i = 0;i < 6;i++)
      //{
        /* Display bar graph at the top left*/
        //LCD_LOCATE(1, 1);
        //LCD_printstring(disp);
        /* Change custom character to be displayed 0->1->2->3->4->5*/
        //disp[char_pos] = (disp[char_pos] + 1);
       //}
			/* if custom character 5 reached (all columns filled) maintain it display */
      //disp[char_pos] = 5;
      /* and move to next position of bar graph*/
      //char_pos++;
	  //}
	
    /* Reset bar graph display to blank*/
    //for (i = 0;i < 8;i++)
      //disp[i] = 0;
			
    /* Blink display and wait for a while*/
    //LCD_DISP_OFF();
    //Delay(300);
		
    //LCD_DISP_ON();
    //Delay(1000);
	}
}

#ifdef USE_FULL_ASSERT

/**
  * @brief  Reports the name of the source file and the source line number
  *   where the assert_param error has occurred.
  * @param file: pointer to the source file name
  * @param line: assert_param error line source number
  * @retval : None
  */
void assert_failed(u8* file, u32 line)
{
  /* User can add his own implementation to report the file name and line number,
     ex: printf("Wrong parameters value: file %s on line %d\r\n", file, line) */

  /* Infinite loop */
  while (1)
  {}
}
#endif

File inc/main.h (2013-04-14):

 /**
  ******************************************************************************
  * @file    main.h
  * @author  MCD Application Team
  * @version V1.0.0
  * @date    16-January-2012
  * @brief   This file contains all the prototypes/macros for main.c.
  ******************************************************************************
  * @attention
  *
  * THE PRESENT FIRMWARE WHICH IS FOR GUIDANCE ONLY AIMS AT PROVIDING CUSTOMERS
  * WITH CODING INFORMATION REGARDING THEIR PRODUCTS IN ORDER FOR THEM TO SAVE
  * TIME. AS A RESULT, STMICROELECTRONICS SHALL NOT BE HELD LIABLE FOR ANY
  * DIRECT, INDIRECT OR CONSEQUENTIAL DAMAGES WITH RESPECT TO ANY CLAIMS ARISING
  * FROM THE CONTENT OF SUCH FIRMWARE AND/OR THE USE MADE BY CUSTOMERS OF THE
  * CODING INFORMATION CONTAINED HEREIN IN CONNECTION WITH THEIR PRODUCTS.
  *
  * FOR MORE INFORMATION PLEASE READ CAREFULLY THE LICENSE AGREEMENT FILE
  * LOCATED IN THE ROOT DIRECTORY OF THIS FIRMWARE PACKAGE.
  *
  * <h2><center>&copy; COPYRIGHT 2011 STMicroelectronics</center></h2>
  ******************************************************************************
  */
/* Define to prevent recursive inclusion -------------------------------------*/
#ifndef __MAIN_H
#define __MAIN_H

/* Includes ------------------------------------------------------------------*/
#include "stm8s.h"

/* Exported types ------------------------------------------------------------*/
void CLK_Configuration(void);
void GPIO_Configuration(void);
void TIM1_Config(void);
void TIM4_Config(void);
void ADC_Config(void);

void KeyRead(void);
u8 Key_thread(void);
 

static void LoadValueIntoSinStruct(void);

 
/* Global variables ----------------------------------------------------------*/
#define TIM4_PERIOD_MS       124

/* On board push button definition */
#define BUTTON_PORT GPIOD
#define BUTTON_PIN GPIO_PIN_7

//定义选择0度或90度座标系
#define CORD_OUT_PORT       GPIOD
#define CORD_0C_PIN         GPIO_PIN_4   
#define CORD_90C_PIN        GPIO_PIN_3
#define CORD_SEL_PORT GPIOD
#define CORD_SEL_PIN  GPIO_PIN_2
#define CORD_SEL_0C   GPIO_WriteLow(CORD_SEL_PORT,CORD_SEL_PIN) 
#define CORD_SEL_90C  GPIO_WriteHigh(CORD_SEL_PORT,CORD_SEL_PIN)


 
#define       nbr_of_samples_half 30
#define       COUNTER             5
#define       INIT_TIM2_ARR       0xCB   //203
#define       INIT_TIM1_CCR1      0x65
#define       AVERAGE_AMP         0x65
 
/* Private typedef -----------------------------------------------------------*/
typedef struct {
  u8 Value[nbr_of_samples_half];
  u8 Index;
  bool Up;
}Sin_Typedef;




#endif /* __MAIN_H */

/******************* (C) COPYRIGHT 2011 STMicroelectronics *****END OF FILE****/

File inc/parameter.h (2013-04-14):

#ifndef __PARAMETER_H
#define __PARAMETER_H
/* Includes ------------------------------------------------------------------*/

/* Private typedef -----------------------------------------------------------*/

/* Private define ------------------------------------------------------------*/
#define AUTORELOAD	0x1999	//sampling period definition (trigg period)
#define NUMB_SAMP	8       //number of samples for SW filtering
#define PEAK_FILTER	8	//  floating spot fall speed filter
#define AD_STAB		20	//  AD stabilization [TIM1 increments] (~10us)

#define MAXTASKS        8
/* Private macro -------------------------------------------------------------*/

/* Private variables ---------------------------------------------------------*/

//定义按键
#define KEY_GPIO_PORT  (GPIOE)
#define KEY_GPIO_PINS  (GPIO_PIN_0 | GPIO_PIN_1 | GPIO_PIN_2 | GPIO_PIN_5 | GPIO_PIN_6)
#define KEY_MENU     GPIO_PIN_1    
#define KEY_FRQ      GPIO_PIN_2
#define KEY_REDUCE   GPIO_PIN_5
#define KEY_PLUS     GPIO_PIN_6

//定义测试类型
#define MODE_R	     0
#define MODE_C       1
#define MODE_L       2

//频率选择 
#define SEL_100      0
#define SEL_1K       1	 
#define SEL_7K8      2

//定义频率控制端口
#define FRQ_GPIO_PORT  (GPIOA)
#define FRQ_GPIO_PINS  (GPIO_PIN_4 | GPIO_PIN_5)
#define FRQ_100 	{GPIO_WriteLow(FRQ_GPIO_PORT, GPIO_PIN_4); \
								GPIO_WriteHigh(FRQ_GPIO_PORT,GPIO_PIN_5); }
#define FRQ_1K  {GPIO_WriteLow(FRQ_GPIO_PORT, GPIO_PIN_4); \
								GPIO_WriteLow(FRQ_GPIO_PORT,GPIO_PIN_5); }
#define FRQ_7K8 {GPIO_WriteHigh(FRQ_GPIO_PORT, GPIO_PIN_4); \
								GPIO_WriteLow(FRQ_GPIO_PORT,GPIO_PIN_5); }

//量程选择 
#define RNG_40       0
#define RNG_1K       1	 
#define RNG_10K      2
#define RNG_100K     3

//定义量程开关
#define RANGE_GPIO_PORT  (GPIOC)
#define RANGE_GPIO_PINS  (GPIO_PIN_5 | GPIO_PIN_6)
#define RANGE_40  {GPIO_WriteLow(RANGE_GPIO_PORT, GPIO_PIN_5); \
								GPIO_WriteLow(RANGE_GPIO_PORT,GPIO_PIN_6); }
#define RANGE_1K   {GPIO_WriteLow(RANGE_GPIO_PORT, GPIO_PIN_5); \
								GPIO_WriteHigh(RANGE_GPIO_PORT,GPIO_PIN_6); }
#define RANGE_10K   {GPIO_WriteHigh(RANGE_GPIO_PORT, GPIO_PIN_5); \
								GPIO_WriteLow(RANGE_GPIO_PORT,GPIO_PIN_6); }
#define RANGE_100K   {GPIO_WriteHigh(RANGE_GPIO_PORT, GPIO_PIN_5); \
								GPIO_WriteHigh(RANGE_GPIO_PORT,GPIO_PIN_6); }

//定义增益开关
#define GAIN_GPIO_PORT (GPIOD)
#define GAIN_GPIO_PINS (GPIO_PIN_5 | GPIO_PIN_6 )
#define GAIN_1 {GPIO_WriteLow(GAIN_GPIO_PORT, GPIO_PIN_5); \
								GPIO_WriteLow(GAIN_GPIO_PORT,GPIO_PIN_6); }
#define GAIN_3 {GPIO_WriteLow(GAIN_GPIO_PORT, GPIO_PIN_5); \
								GPIO_WriteHigh(GAIN_GPIO_PORT,GPIO_PIN_6); }				
#define GAIN_9 {GPIO_WriteHigh(GAIN_GPIO_PORT, GPIO_PIN_5); \
								GPIO_WriteLow(GAIN_GPIO_PORT,GPIO_PIN_6); }								
#define GAIN_27 {GPIO_WriteHigh(GAIN_GPIO_PORT, GPIO_PIN_5); \
								GPIO_WriteHigh(GAIN_GPIO_PORT,GPIO_PIN_6); }

//ADC设置
#define ADC_GPIO_PORT  (GPIOB)
#define ADC_INPUT  GPIO_PIN_3

#define ADC_TIM_PORT   (GPIOC)
#define ADC_TIM_PIN   GPIO_PIN_1


#endif

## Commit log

2013-04-14 改电路为恒流自动电桥，用AD10重画电路图，软件升级为3.0，用的程序是矿坛gyp2000的 1602 V5.5
    [数字部分.SchDoc, 模拟部分.SchDoc, 电源部分.SchDoc]
2013-04-14 数字部份更改CPU为STM8，移植程序到STM平台
    [stm8af52ax.stp, stm8af626x.stp, stm8af62ax.stp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]
2013-04-21 增加TL081电路图PCB制版件
